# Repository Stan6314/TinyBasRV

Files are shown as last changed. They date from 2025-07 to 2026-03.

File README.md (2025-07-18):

Microcomputer TinyBasRV
======================

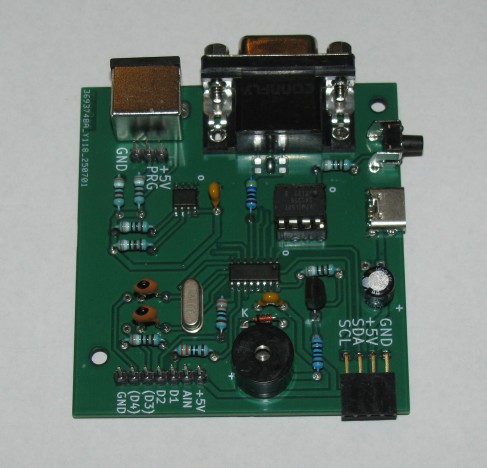
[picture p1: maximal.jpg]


The TinyBasRV microcomputer is a very simple device that even an electrical engineering beginner should be able to assemble and put into operation. It resembles simple 8-bit computers from the 1980s. After assembly, it can be programmed very easily using the Tiny BASIC language, which should be manageable even for those who have never programmed before. The basis is a small 32-bit RISC-V processor cooperating with serial I2C memory, where the user-created program is stored.

A microcomputer is suitable for the first introduction to computing technology when teaching hardware and software. It can be used not only for educational purposes, but can also be used as a control element for simple electronic devices.

Technical data for TinyBasRV
----------------------------

*   TinyBasHW_KiCad - HW documents (schematic and printed circuit board) in KiCad 9.0 format
*   src - Source files for TinyBasRV for CH32V003 created in MounRiver 2.10 environment
*   Bin - Compiled binary content in HEX format for direct loading into CH32V003 memory
*   Manuals - Manuals for HW, Tiny BASIC programming language and its examples and advice for beginners
*   EEPROM_examples - Contents of serial EEPROM memory in HEX format with examples of 8 ready-made Tiny BASIC sample programs for loading into microcomputer memory

Requirements for building and operating a TinyBasRV
---------------------------------------------------

*   Printed circuit board
*   Electrical components according to the list in the TinyBasHW manual
*   WCHLinkE programmer for programming CH32V003
*   Monitor with VGA input
*   Keyboard with PS2 connector
*   5V power supply

Using a microcomputer
---------------------

The assembled microcomputer only requires a 5 V power supply and a VGA monitor and PS2 keyboard connection. It is possible to use both a modern monitor and keyboard...

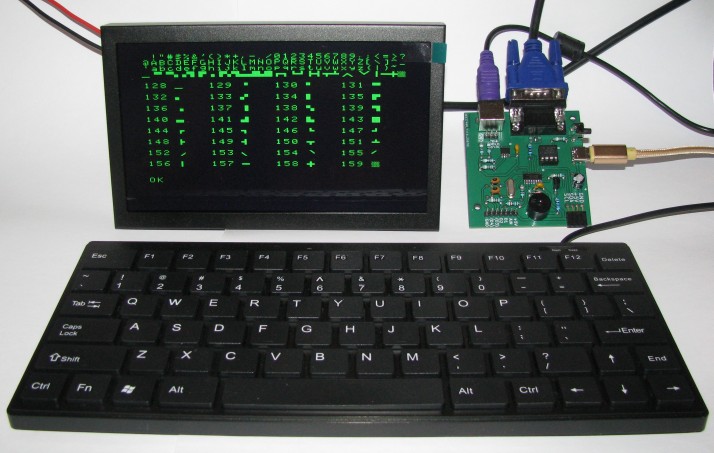
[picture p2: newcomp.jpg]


... so you can also create an old "retro" computer (if you can still find historical computer parts).

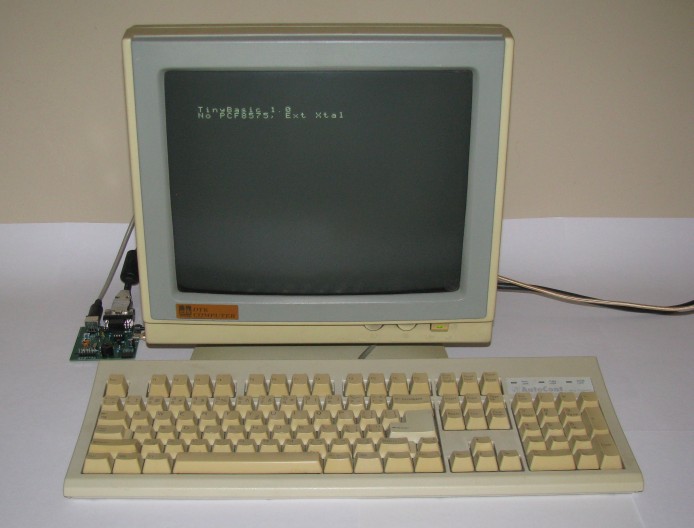
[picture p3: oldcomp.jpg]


After debugging the program, the TinyBasRV microcomputer can work independently without a monitor and keyboard and control, for example, some LED lighting effects.

* * *

Mikropočítač TinyBasRV
======================



Mikropočítač TinyBasRV je velmi jednoduché zařízení, které by měl dokázat sestavit a uvést do provozu i elektrotechnický začátečník. Podobá se jednoduchým 8bitovým počítačům z 80tých let. Po sestavení jej lze velmi jednoduše programovat pomocí jazyka Tiny BASIC, který by měl zvládnout i ten, kdo dříve neprogramoval. Základem je malý 32bitový RISC-V procesor spolupracující se sériovou I2C pamětí, kam se ukládá uživatelem tvořený program.

Mikropočítač je vhodný pro první seznámení s výpočetní technikou při výuce technického i programového vybavení. Může být použit nejen pro výukové účely, ale lze jej nasadit jako řídicí prvek pro jednoduché elektronické přístroje.

Technické podklady pro TinyBasRV
--------------------------------

*   TinyBasHW_KiCad - HW podklady (schéma a plošný spoj) ve formátu programu KiCad 9.0
*   src - Zdrojové soubory k TinyBasRV pro CH32V003 vytvořené v prostředí MounRiver 2.10
*   Bin - Přeložený binární obsah ve formátu HEX pro přímé nahrání do paměti CH32V003
*   Manuals - Manuály pro HW, programovací jazyk Tiny BASIC a jeho příklady a rady pro začátečníky
*   EEPROM_examples - Obsah sériové EEPROM paměti ve formátu HEX s příklady 8 hotových ukázkových programů Tiny BASIC pro nahrání do paměti mikropočítače

Požadavky pro stavbu a provoz TinyBasRV
---------------------------------------

*   Deska plošného spoje
*   Elektrotechnické součástky podle seznamu v manuálu TinyBasHW
*   Programátor WCHLinkE pro naprogramování CH32V003
*   Monitor s VGA vstupem
*   Klávesnice s konektorem PS2
*   Napájecí zdroj 5 V

Použití mikropočítače
---------------------

Sestavený mikropočítač vyžaduje pouze napájecí zdroj 5 V a připojení VGA monitoru a PS2 klávesnice. Je možné použít jak moderní monitor a klávesnici...



... tak si vytvořit i starý "retro" počítač (pokud ještě najdete dnes již historické počítačové díly).



Po odladění programu, může mikropočítač TinyBasRV pracovat samostatně bez monitoru a klávesnice a řídit např. nějaké světelné LED efekty.

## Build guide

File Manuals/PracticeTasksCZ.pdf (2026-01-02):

## Cvičné úlohy pro jazyk Tiny BASIC (ver 1)

Příklad 1:

Zadání:
Vytvořte program pro výpočet plochy obdélníka. Po spuštění programu bude uživatel vyzván, ať zadá délky stran. Pak se vypíše velikost plochy. Vše počítejte s celočíselnými hodnotami.

Rada:
Použijte příkazy PRINT a INPUT. Plocha obdélníka se vypočítá jako součin délek jeho stran.

Příklad řešení:
0 REM Vypocet plochy obdelnika 1 PRINT “Zadej delku stran:\n“ 2 INPUT A; INPUT B
3 PRINT “Plocha je: “ , A*B

Poznámky k řešení:
Příklad by se dal napsat i na jeden řádek:
1 INPUT A; INPUT B; PRINT “Plocha je: “ , A*B

Rev. C

Příklad 2:

Zadání:
Vytvořte program pro výpočet plochy kruhu s přesností na 2 desetinná místa. Po spuštění programu bude uživatel vyzván, ať zadá poloměr kruhu a pak se vypíše velikost plochy.

Rada:
Použijte příkazy PRINT, LET, IF-THEN a INPUT. Tiny BASIC počítá pouze s celými čísly. Použijte pro výpočet plochy hodnotu π jako 314 a pak zobrazte výsledek postupně. Nejprve vypište celou hodnotu získanou dělením 100, znak pro desetinnou čárku a pak zbytek po dělení 100. Nezapomeňte, že zbytek po dělení je nutné zobrazit i s první nulou – např. 08.
Vzorec pro výpočet plochy je známý:

Příklad řešení:
0 REM Vypocet plochy kruhu
1 PRINT “Zadej polomer:\n“
2 INPUT R
3 LET S=R*R*314; LET C=S/100 4 PRINT “Plocha je: “ , C, “.“
5 LET Z=S-C*100
6 IF Z<10 THEN PRINT “0“
7 PRINT Z

Poznámky k řešení:
Tiny BASIC nemá operaci pro mocniny čísel. Proto je druhá mocnina zapsána jako R*R (řádek 3). A také nepracuje s desetinnými čísly. Násobením 314 místo 3,14 získáme výsledek 100krát větší. Abychom dostali celou část výsledku musíme S dělit 100 (řádek 3). Zbytek, který vypočítáme po odečtení celočíselné části násobené 100, pak musíme zobrazit i s případnou první nulou (řádek 6).

Příklad 3:

Zadání:
Vytvořte program, který pod sebe vypíše všechna lichá čísla do 20.

Rada:
Použijte příkazy PRINT, LET, GOTO a IF-THEN

Příklad řešení:
0 REM Licha cisla do 20
1 LET A=1
2 PRINT A, “\n“
3 LET A=A+2
4 IF A<20 THEN GOTO 2

Poznámky k řešení:
Jde o velmi jednoduchý počítaný cyklus. Začínáme od 1 (řádek 1) a postupně čísla vypisujeme na samostatné řádky (řádek 2) se zvětšováním po 2 (řádek 3). Vyhodnocovací podmínka (řádek 4) vrací program na výpis čísla, dokud není dosažena 20.

Příklad 4:

Zadání:
Vytvořte program, který vykresli na obrazovce pravoúhlý trojúhelník ze znaků * vysoký 10 řádků.

Rada:
Použijte příkazy PUTCH, LET, GOTO a IF-THEN. Znak pro nový řádek má hodnotu 10 a znak * má hodnotu 42.

Příklad řešení:
0 REM Trojuhelnik z *
1 PUTCH 10
2 LET A=1; REM Pocita radky
3 LET B=1; REM Hvezdy na radku 4 PUTCH 42; LET B=B+1
5 IF B<=A THEN GOTO 4
6 PUTCH 10; LET A=A+1
7 IF A<11 THEN GOTO 3

Poznámky k řešení:
Jsou zde použity 2 počítané cykly vnořené do sebe. V proměnné A se počítají řádky (řádky 2,6,7) a v proměnné B se počítají znaky vypisované na řádku (řádky 3,4,5).

Příklad 5:

Zadání:
Vytvořte program, který vykresli na obrazovce čtverec o délce strany 10 znaků.

Rada:
Použijte příkazy PUTCH, PRINT, LET, GOTO a IF-THEN. Abyste si ušetřili práci, použijte pro vykreslení vodorovné čáry podprogram s příkazy GOSUB a RETURN. Nezapomeňte program ve správném bodě ukončit příkazem END.
Znak pro vymazání displeje má hodnotu 12, nový řádek 10, levý horní roh 144, pravý horní roh 145, levý dolní roh 146, pravý dolní roh 147, svislá čára 156 a vodorovná čára 157.

Příklad řešení:
0 REM Ctverec
1 PUTCH 12
2 LET A=1; REM Pocita radky 3 PUTCH 144; GOSUB 10
4 PUTCH 145; PUTCH 10
5 PUTCH 156; PRINT “ “
6 PUTCH 156; PUTCH 10; LET A=A+1 7 IF A<8 THEN GOTO 5
8 PUTCH 146; GOSUB 10
9 PUTCH 147; PUTCH 10; END
10 REM Vodorovna cara
11 LET I=1
12 PUTCH 157; LET I=I+1
13 IF I<9 THEN GOTO 12
14 RETURN

Poznámky k řešení:
Řádky 3 a 4 vykreslí horní stranu čtverce, řádky 8 a 9 spodek čtverce. Využívá se podprogram na řádcích 10 až 14, který dělá vodorovnou čáru. Řádky 5, 6 a 7 vykreslí svislé čáry. Počet mezer v příkazu PRINT na řádku 5 musí být 8, aby se vyprázdnilo tělo čtverce.

Příklad 6:

Zadání:
Vytvořte program, který umožní posunovat znak X po obrazovce. Začíná se uprostřed obrazovky a stisknutí klávesy 2 znak X posune dolů, 4 vlevo, 6 vpravo a 8 nahoru.

Rada:
Použijte příkaz PUTCH s využitím jeho parametrů, CURSOR, INKEY, GOTO a IF-THEN.
Znak pro vymazání displeje má hodnotu 12, znak X je 88, prázdný znak je 32, 2 je 50, 4 je 52, 6 je 54 a 8 je 56.

Příklad řešení:
0 REM Posun X
1 PUTCH 12
2 CURSOR 400; PUTCH .88
3 INKEY K
4 IF K=50 THEN PUTCH v32; PUTCH .88 5 IF K=52 THEN PUTCH <32; PUTCH .88 6 IF K=54 THEN PUTCH >32; PUTCH .88 7 IF K=56 THEN PUTCH ^32; PUTCH .88
8 GOTO 3

Poznámky k řešení:
Program nejprve vyčistí obrazovku a umístí doprostřed displeje (pozice 400) znak X pomocí příkazu PUTCH. Symbol tečky zajistí, že kurzor zůstane na dané pozici. Když uživatel stiskne správnou klávesu, nejprve se vymaže stará pozice prázdným znakem a posune se kurzor na novou pozici (směr určuje symbol před hodnotou 32). Na nové pozici se pak vypíše X a ponechá kurzor.

Příklad 7:

Zadání:
Vytvořte program, který bude automaticky „hrát ping-pong“. Míček v podobě písmene o bude poletovat na řádku z levé strany na pravou stranu a naopak. Na kraji displeje se vždy odrazí a vrátí zpět.

Rada:
Použijte příkaz PUTCH s využitím parametrů, CURSOR, DELAY, GOTO a IF-THEN.
Znak pro vymazání displeje má hodnotu 12, znak o je 111, prázdný znak je 32.
Pozice uprostřed prostředního řádku má hodnotu 400, znak na levém okraji 384, vpravo 415.

Příklad řešení:
0 REM Ping-pong
1 PUTCH 12; LET C=400
2 CURSOR C; PUTCH .111
3 LET D=1
4 DELAY 100; PUTCH .32
5 LET C=C+D; CURSOR C; PUTCH .111 6 IF C=415 THEN LET D=-1
7 IF C=384 THEN LET D=1
8 GOTO 4

Poznámky k řešení:
Nejprve se program nastaví do výchozí pozice a směr pohybu míčku v proměnné D se určí na hodnotu 1 – tj. míček poletí vpravo(řádky 1 až 3). Ve smyčce, která začíná na řádku 4, se chvíli počká, smaže starý obraz míčku a pak se posune míček podle hodnoty v D na novou pozici. Řádky 6 a 7 hlídají dosažení kraje obrazovky a mění směr letu tam (D=1), nebo zpět (D=-1).

Příklad 8:

Zadání:
Napište program, který zahraje melodii podle not na obrázku. Na začátku uživatel zadá dobu trvání 1/8 noty v rozmezí 200 až 400 milisekund.

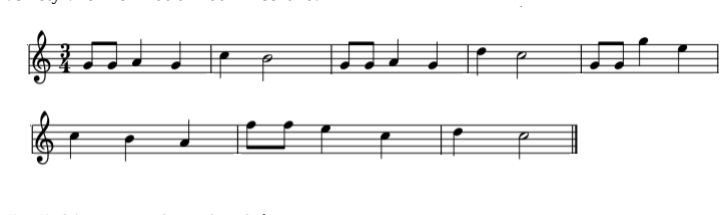
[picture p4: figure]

Přibližné frekvence základních tónů:
c‘: 262 | d‘: 294 | e‘: 330 | f‘: 349 | g‘: 392 | a‘: 440 | h‘: 494
c“: 523 | d“: 587 | e“: 659 | f“: 698 | g“: 784 | a“: 880 | h“: 989

Rada:
Použijte příkaz BEEP s využitím parametrů, INPUT, GOTO a IF-THEN. Pokud se v melodii objevují stejné pasáže, můžete použít podprogram GOSUB a RETURN, abyste nemuseli opisovat stejné části. Nezapomeňte program ukončit příkazem END.

Příklad řešení:
0 REM Melodie
1 PRINT “Zadej tempo:\n“
2 INPUT T
3 IF T<200 THEN GOTO 1
4 IF T>400 THEN GOTO 1
5 GOSUB 15
6 BEEP 523,2*T; BEEP 494,4*T; GOSUB 15 7 BEEP 587,2*T; BEEP 523,4*T; BEEP 392,T 8 BEEP 392,T; BEEP 784,2*T; BEEP 659,2*T
9 BEEP 523,2*T; BEEP 494,2*T; BEEP 440,2*T 10 BEEP 698,T; BEEP 698,T; BEEP 659,2*T
11 BEEP 523,2*T; BEEP 587,2*T; BEEP 523,4*T 12 END
15 BEEP 392,T; BEEP 392,T; BEEP 440,2*T
16 BEEP 392,2*T; RETURN

Poznámky k řešení:
Uživatel je nejprve vyzván k zadání tempa a je zkontrolováno povolené rozmezí hodnot (řádky 1 až 4). Protože se první čtyři tóny opakují ve třetím taktu, je použit podprogram na řádcích 15 a 16. Jednotlivé tóny jsou zadány frekvencí a dobou trvání. Čtvrťová nota je dvojnásobná a půlová čtyřnásobná proti zadané době osminové noty.

Příklad 9:

Zadání:
Napište program pro vytvoření velmi jednoduchého klavíru. Po stisknutí klávesy 1 až 9 zahraje po dobu 200 až 600 milisekund (čas se zadá po startu) tón c‘ až d“.
Přibližné frekvence základních tónů:
c‘: 262 | d‘: 294 | e‘: 330 | f‘: 349 | g‘: 392 | a‘: 440 | h‘: 494
c“: 523 | d“: 587

Rada:
Použijte příkaz BEEP s využitím parametrů, INPUT, INKEY, GOTO a IF-THEN. Zkuste využít toho, že klávesy 1 až 9 vrací v příkazu INKEY hodnoty 49 až 57. Pak můžete vypočítat potřebný skok v příkazu GOTO.

Příklad řešení:
0 REM Piano
1 PRINT “Zadej dobu tonu:\n“ 2 INPUT T
3 IF T<200 THEN GOTO 1
4 IF T>600 THEN GOTO 1
5 INKEY K
6 IF K<49 THEN GOTO 5
7 IF K>57 THEN GOTO 5
8 GOTO K-40
9 BEEP 262,T; GOTO 5
10 BEEP 294,T; GOTO 5
11 BEEP 330,T; GOTO 5
12 BEEP 349,T; GOTO 5
13 BEEP 392,T; GOTO 5
14 BEEP 440,T; GOTO 5
15 BEEP 494,T; GOTO 5
16 BEEP 523,T; GOTO 5
17 BEEP 587,T; GOTO 5

Poznámky k řešení:
Uživatel je nejprve vyzván k zadání doby tónu a je zkontrolováno povolené rozmezí hodnot (řádky 1 až 4). Ve smyčce, která začíná na řádku 5 se nejprve zkontroluje, zda klávesa patří mezi povolené a pak se vypočítá na řádku 8 skok na řádek s odpovídajícím tónem. Hodnota první povolené číslice 49 musí zamířit na řádek 9, proto se odečítá hodnota 40.

Příklad 10:

Zadání:
Vytvořte program, který bude představovat losovací zařízení pro čísla 1 až 49. Vždy po stisknutí libovolné klávesy zobrazí náhodné číslo z uvedeného rozsahu.

Rada:
Použijte příkazy TIME, INKEY, PRINT, GOTO a IF-THEN.
Po stisknutí klávesy vezměte aktuální čas. Jeho zbytek po dělení 49 bude dostatečně náhodné číslo. Nezapomeňte, že zbytek po dělení 49 je v rozsahu 0 až 48. Získanou hodnotu je potřeba zvýšit o 1.

Příklad řešení:
0 REM Nahodne cislo
1 INKEY K
2 IF K=0 THEN GOTO 1
3 TIME T; LET A=T/49
4 PRINT T-A*49+1, “\n“
5 GOTO 1

Poznámky k řešení:
Na řádcích 1 a 2 se čeká na stisknutí libovolné klávesy. V okamžiku, kdy uživatel stiskne klávesu se naplní proměnná T příkazem TIME. Hodnota získaná příkazem TIME se mění přibližně 32000krát za sekundu. Protože potřebujeme náhodná čísla do 49, vypočítáme zbytek po dělení 49. Výsledek zvětšený o 1 zobrazíme.

Příklad 11:

Zadání:
Vytvořte program ukazující čas uplynulý od spuštění počítače ve formě HH:MM:SS.

Rada:
Použijte příkazy TIME, PRINT, PUTCH, CURSOR, GOTO a IF-THEN.
Pokud hodnotu získanou příkazem TIME podělíte 31914, získáte čas od spuštění počítače v sekundách. Získaný čas pak stačí dělit 3600, abyste dostali počet uplynulých hodin. Ze zbytku pak dělením 60 získáte minuty. Nezapomeňte, že v zadání je zobrazení čísla na 2 místa. Nestačí vypsat jenom např. 5, je třeba zobrazit jako 05. Na to se může hodit podprogram s GOSUB a RETURN. Znak : má hodnotu 58, znak 0 má hodnotu 48.

Příklad řešení:
0 REM Hodiny
1 PUTCH 12
2 DELAY 300
3 TIME T; LET S=T/31914
4 LET A=S/3600; LET S=S-A*3600 5 CURSOR 0; GOSUB 10
6 LET A=S/60; LET S=S-A*60
7 PUTCH 58; GOSUB 10
8 LET A=S; PUTCH 58; GOSUB 10 9 GOTO 2
10 REM Vypis z A na 2 mista
11 IF A<10 THEN PUTCH 48
12 PRINT A; RETURN

Poznámky k řešení:
Čas získaný příkazem TIME podělíme hodnotou 31914, abychom získali celkový čas v sekundách. Hodiny do proměnné A získáme dělením 3600. Ve zbytku po celočíselném dělení zůstanou minuty a sekundy. Celočíselným dělením 60 dostaneme minuty a zbytek z výpočtu minut jsou sekundy. Vše musíme zobrazovat na 2 místa, takže doplňujeme případnou první nulu u jednociferných čísel při zobrazování hodnoty z A v podprogramu (řádek 11).

Příklad 12:

Zadání:
Vytvořte pomocí počítače „kuchyňskou minutku“. Po startu programu uživatel zadá čas od 1 do 99 minut. Po zadání začne na displeji odpočítávání po minutách a po dosažení 0 se ozve 10 sekund signál.

Rada:
Použijte příkaz TIME, BEEP, INPUT, PRINT, GOTO a IF-THEN. Po zadání požadovaného času si můžete vypočítat čas, při kterém časování skončí. Cílový čas získáte přičtením počtu minut násobených 60*31914 (sekundy v minutě krát počet tiků za sekundu = 1914840) k aktuálnímu času.

Příklad řešení:
0 REM Minutka
1 PRINT “Zadej cas [min]:\n“ 2 INPUT T
3 IF T<1 THEN GOTO 1
4 IF T>99 THEN GOTO 1
5 TIME C; LET C=C+T*60*31914 6 PUTCH 12
7 DELAY 300
8 TIME T; LET D=C-T
9 IF D<0 THEN BEEP 800,10000; END 10 CURSOR 0; PRINT D/1914840, “ “
11 GOTO 7

Poznámky k řešení:
Uživatel je nejprve vyzván k zadání doby a je zkontrolováno povolené rozmezí hodnot (řádky 1 až 4). Po správném zadání je do proměnné C uložen cílový čas, který vypočítáme jako aktuální čas s dobou zadanou uživatelem vynásobenou 31914 (počet tiků za sekundu) a 60 (počet sekund v minutě). Ve smyčce, která začíná na řádku 7, chvíli čekáme, protože není nutno zobrazovat hodnoty tak rychle, že by to uživatel stejně nepostřehl. Na řádku 8 zjistíme rozdíl mezi cílovým a aktuálním časem. Při záporném výsledku časování ukončíme. Jinak rozdíl zobrazíme. Konstanta 1914840 vznikne vynásobením 60*31914.

Příklad 13:

Zadání:
Naprogramujte hru „Lepší postřeh“ pro dva a více hráčů. Po stisknutí klávesy čeká 5 sekund, přičemž start časování je zahájen *. Pak zobrazí na displeji cílový znak. Klávesa, která byla zmáčknutá jako první po zobrazení cílového znaku, bude označena jako vítěz.

Rada:
Použijte příkazy INKEY, DELAY, PUTCH, PRINT, GOTO a IF-THEN. Při tvorbě programu nezapomeňte na to, že musíte zkontrolovat, zda hráč nezmáčknul klávesu před zobrazením cílového znaku.
Znak * má hodnotu 42, cílový znak má hodnotu 143.

Příklad řešení:
0 REM Lepsi postreh
1 PRINT “\nStart hry\n“
2 INKEY K
3 IF K=0 THEN GOTO 2
4 PUTCH 42; DELAY 5000; INKEY K 5 PUTCH 143; IF K>0 THEN GOTO 10
6 INKEY K
7 IF K=0 THEN GOTO 6
8 PRINT “\nVitez: “; PUTCH K; DELAY 2000 9 GOTO 1
10 PRINT “\nProhral: “; PUTCH K; DELAY 2000
11 GOTO 1

Poznámky k řešení:
Na řádcích 1 až 3 počkáme na start hry. Pak zobrazíme *, čekáme 5 sekund a sejmeme, zda někdo nestiskl klávesu předčasně (řádek 4). Na řádku 5 zobrazíme cílový znak a zkontrolujeme předčasné stisknutí klávesy. Je-li vše v pořádku, na řádcích 6 a 7 čekáme na stisknutí klávesy a na řádku 8 vyhlásíme vítěze.

Příklad 14:

Zadání:
Vytvořte program pro akustický generátor. Uživatel zadá frekvenci požadovaného tónu v rozsahu 100 až 4000 Hz a dokud nebude program ukončen, počítač píská zadaným tónem.

Rada:
Použijte příkazy BEEP, INPUT, PRINT, GOTO a IF-THEN.
Aby bylo možné program zastavit zadáním příkazu END, použijte v časovém parametru u příkazu BEEP nějakou přijatelnou hodnotu v rozsahu jednotek sekund.

Příklad řešení:
0 REM Zvukovy generator
1 PRINT “Zadej frekv. 100-4000\n“ 2 INPUT F
3 IF F<100 THEN GOTO 1
4 IF F>4000 THEN GOTO 1
5 BEEP F,5000
6 GOTO 5

Poznámky k řešení:
Uživatele nejprve vyzveme k zadání frekvence a je zkontrolováno povolené rozmezí hodnot (řádky 1 až 4). Pak je ve smyčce na řádcích 5 a 6 trvale pouštěn tón o zadané frekvenci.

Příklad 15:

Zadání:
Napište program, ve kterém uživatel zadá nějaké jméno ukončené klávesou Enter. Počítač pak vypíše, že jméno je jeho přítel. Maximální délka jména může být 30 znaků.

Rada:
Použijte příkazy INKEY, PRINT, PUTCH, GOTO a IF-THEN. Zadávané jméno je výhodné ukládat do proměnných v poli @. Počítejte si přitom počet uložených písmen.

Příklad řešení:
0 REM Pritel pocitace
1 LET I=0; PRINT “\nZadej jmeno:\n“ 2 INKEY K
3 IF K=0 THEN GOTO 2
4 IF K=10 THEN GOTO 10
5 PUTCH K; LET @I=K; LET I=I+1 6 IF I=30 THEN GOTO 10
7 GOTO 2
10 LET J=0; PUTCH 10
11 PUTCH @J; LET J=J+1
12 IF J<I THEN GOTO 11
13 PRINT “ je muj pritel\n“

Poznámky k řešení:
Řádky 2 a 3 čekají na zadání znaku. Řádek 4 kontroluje, zda nebylo zadávání ukončeno klávesou Enter. Na řádku 5 je znak uložen do pole. Řádek 6 kontroluje maximální povolenou délku jména. Na řádcích 10 až 12 je jméno opět vypsáno.

Příklad 16:

Zadání:
Vytvořte program pro ovládání LED připojené k výstupu D1 pomocí klávesnice. První zmáčknutí libovolné klávesy LED rozsvítí, druhé zhasne, další opět rozsvítí atd.

Doplňkový HW:
Na výstup D1 připojte LED s rezistorem podle následujícího obrázku. Červená barva LED bude vhodná pro následující úlohu.

Rada:

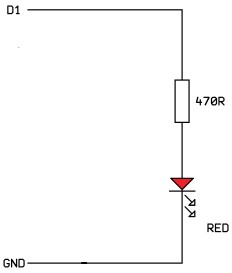
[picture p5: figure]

Použijte příkazy INKEY, DOUT, GOTO a IF-THEN. Příkaz DOUT 1,1 pak LED rozsvítí a DOUT 0,1 ji zhasne.
Protože program nemusí být rychlý, můžete do cyklu čekání na stisk klávesy vložit drobné zpoždění příkazem DELAY.

Příklad řešení:
0 REM Ovladani LED
1 LET L=0
2 DELAY 100; INKEY K
3 IF K=0 THEN GOTO 2
4 IF L=0 THEN GOTO 6
5 LET L=0; DOUT 0,1; GOTO 2
6 LET L=1; DOUT 1,1; GOTO 2

Poznámky k řešení:
Proměnná L ukládá aktuální hodnotu výstupu, abychom věděli, jak příště výstup změnit. Na řádcích 2 a 3 se čeká na stisk klávesy. Řádek 4 rozhodne podle stavu L, zda se LED rozsvítí nebo zhasne.

Příklad 17:

Zadání:
Vytvořte program, který z TinyBasRV udělá ovládání výstražných světel na železničním přejezdu i se zvukovou signalizací.

Doplňkový HW:
Na výstupy D1 a D2 připojte dvě LED (nejlépe červené) s rezistory podle následujícího obrázku.

Rada:

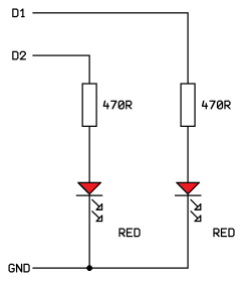
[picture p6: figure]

Použijte příkazy BEEP, DELAY, DOUT a GOTO. Zvukovou signalizaci si vyzkoušejte a upravte podle vlastních představ.

Příklad řešení:
0 REM Zeleznice - vystraha
1 DOUT 1,1; DOUT 0,2
2 BEEP 2000,100; BEEP 800,200; DELAY 200 3 DOUT 0,1; DOUT 1,2
4 BEEP 2000,100; BEEP 800,200; DELAY 200
5 GOTO 1

Poznámky k řešení:
Řádky 1 a 3 rozsvítí vždy pouze jednu z obou LED. Na řádcích 2 a 4 je generováno stejné zvukové znamení. Uvedený příklad jen velmi vzdáleně připomíná cinkání zvonce. Můžete je ladit a upravovat podle svého ucha...

Příklad 18:

Zadání:
Vytvořte program pro měření vstupního napětí na vstupu AIN v mV. Na vstup přiveďte napětí z běžce potenciometru, které bude zobrazováno s periodou ½ sekundy.

Doplňkový HW:
Na výstup AIN připojte lineární potenciometr s hodnotou odporu v rozmezí 1 až 100 kΩ podle následujícího obrázku.

Rada:

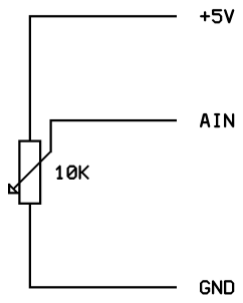
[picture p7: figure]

Použijte příkazy AINP, DELAY, CURSOR, PRINT a GOTO. Hodnota získaná z A/D převodníku je v rozsahu 0 až 1023. To představuje napětí 0 až 5V – tedy 0 až 5000 mV. Abychom přepočítali rozsah A/D převodníku na mV, musíme hodnotu nejprve vynásobit 5000 a pak dělit 1023.

Příklad řešení:
0 REM Analog vstup mV
1 PUTCH 12
2 CURSOR 397; AINP A
3 PRINT A*5000/1023, “ mV “ 4 DELAY 500
5 GOTO 2

Poznámky k řešení:
Na řádku 2 se nejprve nastaví kurzor přibližně do středu obrazovky a pak se změří napětí na vstupu AIN. Přepočet se provede při výpisu hodnoty v příkaze PRINT podle návodu v odstavci Rada. Po výpisu jednotek jsou ještě doplněny 3 mezery, aby se vymazal případný delší zápis z minulého měření.

Příklad 19:

Zadání:
Upravte počítač TinyBasRV tak, aby pracoval jako jednoduchý voltmetr s rozsahem do 50 V. Napětí bude zobrazováno s periodou ½ sekundy a s rozlišením na 2 desetinná místa.

Doplňkový HW:
Na výstup AIN připojte vstupní odporový dělič s rezistory s poměrem odporů 9:1. Ideální by bylo např. 900 kΩ a 100 kΩ. Hodnota 900 kΩ je ale mimo běžnou řadu dostupných rezistorů. Můžete použít nejbližší hodnotu 910 kΩ z řady E24. V nouzi lze použít i 1 MΩ a upravit konstantu v programu.

Rada:

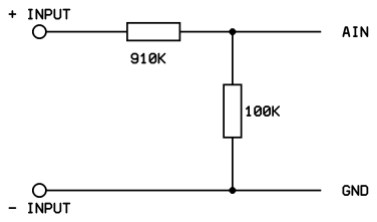
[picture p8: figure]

Použijte příkazy AINP, DELAY, CURSOR, PUTCH, PRINT, GOTO a IF-THEN. Hodnota získaná AINP z A/D převodníku je v rozsahu 0 až 1023. To představuje napětí 0 až 50V (musíme zobrazit 0.00 až 50.00 V). Abychom přepočítali rozsah A/D převodníku na V, je třeba hodnotu nejprve vynásobit 5000 a pak dělit 1023. Výsledné číslo zobrazíme s desetinou tečkou mezi číslicemi. Násobící konstanta 5000 je ideální případ, kdy se předpokládá přesné referenční napětí v mikropočítači a přesné hodnoty odporu obou rezistorů v děliči. V praxi se to bude lišit. Proto je potřeba u konkrétního kusu počítače tuto hodnotu upravit tak, aby zobrazené napětí se co nejvíce blížilo napětí změřenému referenčním voltmetrem.

Příklad řešení:
0 REM Voltmetr 50V
1 PUTCH 12; LET K=5320
2 CURSOR 397; AINP A
3 LET V=A*K/1023; LET C=V/100 4 LET Z=V-C*100
5 PRINT C, “.“
6 IF Z<10 THEN PRINT “0“
7 PRINT Z
8 DELAY 500
9 GOTO 2

Poznámky k řešení:
Na řádku 1 je nastavena přepočtová konstanta, kterou si musíte upravit podle konkrétního kusu počítače a vstupního odporového děliče. Další postup již kopíruje instrukce uvedené v odstavci Rada. Nejprve je vypsána celá část z proměnné C a pak zbytek po dělení 100 ze Z. Pokud je zbytek menší než 10, je nutné doplnit úvodní nulu (řádek 6).

Příklad 20:

Zadání:
Pomocí expanderu PCF8575 připojeného k TinyBasRV vyrobte běžící světlo na řadě LED připojených k výstupům expanderu.

Doplňkový HW:
Na výstupy modulu s expanderem PSC8575 připojte více LED podle obrázku. Záleží na množství LED, které máte k dispozici, maximálně je možné připojit 16 LED.

Rada:

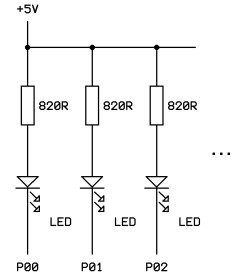
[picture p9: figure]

Použijte příkazy I2CW, DELAY, LET, GOTO a IF-THEN. Pokud chcete rozsvítit první LED, musíte do expanderu poslat binární číslo b1111111111111110 nebo dekadicky -2. Druhá LED vyžaduje poslat binární číslo b1111111111111101 nebo dekadicky -3. Další by bylo binární číslo b1111111111111011 nebo dekadicky -5. Rozsvícení LED se posune na další pozici vždy vynásobením 2 a přičtením 1.
Po rozsvícení poslední LED se musí světlo vrátit na začátek.

Příklad řešení (pro 8 LED): 0 REM Bezicich 8 LED
1 LET A=-2
2 I2CW A; DELAY 200
3 LET A=A*2+1
4 IF A < -300 THEN LET A=-2
5 GOTO 2

Poznámky k řešení:
Program postupuje podle instrukcí uvedených v odstavci Rada. Po daný příklad bylo použito pouze 8 LED, při dosažení hodnoty menší než -300 se hodnota v A vrátí na začátek. Poslání čísla -257 do expanderu (poslední odeslané v cyklu) na chvíli vypne všech 8 LED. Pokud byste to nechtěli, zmenšete podmínku např. na A<-150.

Příklad 21:

Zadání:
Napište program, který pomocí expanderu PCF8575 připojeného k TinyBasRV rozsvítí po stisknutí klávesy 0 až 9 určený počet LED (vámi zvolený obraz).

Doplňkový HW:
Na výstupy modulu s expanderem PSC8575 připojte více LED podle obrázku. Záleží na množství LED, které máte k dispozici, maximálně je možné připojit 16 LED.

Rada:

Použijte příkazy I2CW, DELAY, INKEY, GOTO a IF-THEN. Pro jednotlivé číslice si můžete určit libovolný vzorek rozsvícených LED. Např. po stisknutí klávesy 1 se rozsvítí každá lichá LED příkazem I2CW b1010101010101010, klávesa 2 rozsvítí dolní polovinu LED příkazem I2CW b1111111100000000 atd.
Klávesy 0 až 9 vrací v příkazu INKEY hodnoty 48 až 57.

Příklad řešení:
0 REM Vzory z LED
1 DELAY 100; INKEY K
2 IF K<48 THEN GOTO 1
3 IF K>57 THEN GOTO 1
4 GOTO K-43
5 I2CW b1100110011001100; GOTO 1 6 I2CW b1010101010101010; GOTO 1 7 I2CW b1111111100000000; GOTO 1 8 I2CW b1111100001100101; GOTO 1 9 I2CW b0000000011001100; GOTO 1 10 I2CW b1100110000000000; GOTO 1 11 I2CW b1110111011101110; GOTO 1 12 I2CW b1101110111011101; GOTO 1 13 I2CW b1011101110111011; GOTO 1
14 I2CW b0111011101110111; GOTO 1

Poznámky k řešení:
Nejprve se na řádcích 1, 2 a 3 zajistí přijetí pouze povolené číselné klávesy. Řádek 4 pak zajistí odskok na patřičný vzorek rozsvícených LED s návratem na začátek.

Příklad 22:

Zadání:
Naprogramujte měřič postřehu uživatele. Po stisknutí klávesy čeká program náhodný počet sekund (1 až 10), přičemž start časování je zahájen *. Pak zobrazí na displeji cílový znak. Uživatel musí co nejrychleji zmáčknout libovolnou klávesu. Na displeji se zobrazí reakční čas v milisekundách.

Rada:
Použijte příkazy INKEY, TIME, DELAY, PUTCH, PRINT, GOTO a IF-THEN. Při tvorbě programu nezapomeňte na to, že musíte zkontrolovat, zda hráč nezmáčknul klávesu před zobrazením cílového znaku. Pro měření času v milisekundách budeme počítat, že TIME vrací každou milisekundu hodnotu o 32 větší.
Znak * má hodnotu 42, cílový znak má hodnotu 143.

Příklad řešení:
0 REM Meric postrehu
1 PRINT “\nStart\n“
2 INKEY K
3 IF K=0 THEN GOTO 2
4 TIME T; LET C=T/10
5 LET D=T-C*10+1; LET D=D*1000 6 PUTCH 42; DELAY D
7 INKEY K; PUTCH 143; TIME S 8 IF K>0 THEN GOTO 14
9 INKEY K
10 IF K=0 THEN GOTO 9
11 TIME E; LET R=E-S
12 PRINT “\nReakce: “, R/32 13 PRINT “ milisec“; GOTO 1 14 PRINT “\nPredcasne!“
15 GOTO 1

Poznámky k řešení:
Řádky 2 a 3 čekají na start měření. Pak se získá pomocí příkazu TIME a zbytku po dělení 10 náhodný čas, který se uloží do proměnné D v milisekundách (řádky 4 a 5). Na řádku 6 se zobrazí * a provede čekání. Řádek 7 sejme stav kláves, zobrazí cílový znak a uloží začáteční čas pro měření postřehu. Na řádku 8 se zkontroluje případné předčasné stisknutí klávesy. Řádky 9 a 10 čekají na reakci uživatele. Čas, kdy zareagoval se uloží do E a pak na řádcích 11, 12 a 13 se výsledek vypíše.

Příklad 23:

Zadání:
Máte-li možnost připojit k TinyBasRV jehličkovou tiskárnu s paralelním portem přes expander PCF8575, vytvořte z ní jednoduchý psací stroj.

Doplňkový HW:
Na výstupy modulu s expanderem PCF8575 připojte konektor Cannon 25 samici podle obrázku.

Rada:

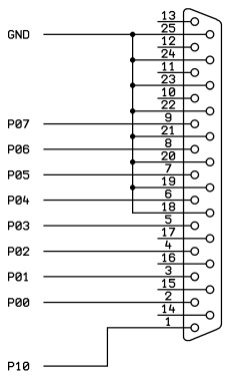
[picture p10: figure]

Použijte příkazy I2CW, DELAY, INKEY, GOTO a BEEP. Příkaz BEEP se použije pro zvukovou signalizaci stisknutí klávesy krátkým pípnutím. Není nutné jej použít.
Na vývodu 1 paralelního portu je signál STROBE ovládaný výstupem P10, který potvrdí a zapíše data do tiskárny. Aktivní hodnota je logická 0. Po zapsání dat, je nutné tento signál vrátit do klidové hodnoty 1. To lze nejsnáze udělat zapsáním hodnoty o 256 větší než zapisovaná data.

Příklad řešení:
0 REM Psaci stroj
1 INKEY K
2 IF K=0 THEN GOTO 1
3 I2CW K; PUTCH K
4 DELAY 10
5 I2CW K+256; BEEP 1000,50
6 GOTO 1

Poznámky k řešení:
Řádky 1 a 2 čekají na stisk klávesy. Řádek 3 pošle znak do tiskárny a okopíruje ho na displej. Na řádku 4 se chvíli počká (pro případ pomalé reakce tiskárny). Na řádku 5 se musí nastavit signál STROBE pro tiskárnu zpět na logickou 1 (hodnota znaku se zvýší o 9tý bit nastavený na 1) a krátce se pípne.

Příklad 24:

Zadání:
Vytvořte z TinyBasRV jednoduchou celočíselnou kalkulačku. Uživatel zadá první číslo, pak operand (+ - * /) a na závěr druhé číslo. Na displeji se objeví vypočítaný výsledek ve tvaru např. 256*2=512.

Rada:
Použijte příkazy INPUT, INKEY, PRINT, PUTCH, GOTO a IF-THEN. Znaky operandů mají následující hodnoty:
+ | 43 | - | 45 | * | 42 | / | 47
Nezapomeňte, že nulou nedělíme!

Příklad řešení:
0 REM Kalkulacka
1 PUTCH 10; INPUT A
2 INKEY K
3 IF K=42 THEN GOTO 8
4 IF K=43 THEN GOTO 8
5 IF K=45 THEN GOTO 8
6 IF K=47 THEN GOTO 8
7 GOTO 2
8 PUTCH K; PUTCH 10; INPUT B;
9 PRINT A; PUTCH K; PRINT B
10 IF K=43 THEN PRINT “=“,A+B; GOTO 1
11 IF K=45 THEN PRINT “=“,A-B; GOTO 1
12 IF K=42 THEN PRINT “=“,A*B; GOTO 1
13 IF B=0 THEN PRINT “ Nulou nelze!“; GOTO 1
14 PRINT “=“,A/B; GOTO 1

Poznámky k řešení:
První hodnota se uloží do proměnné A na řádku 1. Pak se na řádcích 3 až 7 čeká na typ operace. Na řádku 8 vytiskneme znak operace a počkáme na druhou hodnotu. Řádky 10 až 14 provedou výpočet podle stavu K, přičemž se na řádku 13 zkontroluje, zda se nebude dělit 0.

Příklad 25:

Zadání:
Napište program pro hádání tajného čísla 0 až 99. Po startu si počítač vybere náhodné číslo a hráč má toto číslo uhodnout na co nejmenší počet pokusů. Po každém pokusu počítač uvede, zda je tajné číslo větší nebo menší než to, které zadal hráč.

Rada:
Použijte příkazy INPUT, PRINT, TIME, LET, GOTO a IF-THEN. Nejprve si vygenerujte pomocí příkazu TIME a zbytku po dělení 100 náhodné číslo.

Příklad řešení:
0 REM Hadani cisla
1 TIME T; LET C=T/100; LET X=T-C*100 2 LET P=0; PRINT “\nHadej cislo\n“
3 INPUT A; LET P=P+1
4 IF A=X THEN GOTO 8
5 IF A>X THEN GOTO 7
6 PRINT P,“. Hadej vic\n“; GOTO 3
7 PRINT P,“. Hadej mene\n“; GOTO 3
8 PRINT “Uhodl jsi na “, P, “ pokusu\n“

Poznámky k řešení:
Na řádku 1 se pomocí příkazu TIME a zbytku po celočíselném dělení 100 uloží do proměnné X náhodně generované hádané číslo. Na řádcích 2 a 3 je uživatel vyzván k pokusu uhodnout číslo a v proměnné P se počítají provedené pokusy. Řádky 4 a 5 kontrolují úspěšnost pokusu a na zbývajících řádcích se vypisuje pokyn, kam směřovat další odhad nebo ukončení programu s výsledkem.

Příklad 26:

Zadání:
Vytvořte z TinyBasRV jednoduchý kódový zámek. Zadá-li uživatel na klávesnici správnou posloupnost 4 nebo 5 číslic, na výstupu D1 se na 3 sekundy objeví logická 1 a zazní zvukový signál.

Rada:
Použijte příkazy INKEY, LET, DOUT, BEEP, GOTO a IF-THEN. Počet kódových číslic si můžete zvolit sami. Tajnou číselnou kombinaci si uložte do pole @ a každá správně uhodnutá číslice posune ukazatel v poli na vyšší hodnotu. Při chybě se ukazatel vrátí na počátek pole.
Klávesy 0 až 9 vrací v příkazu INKEY hodnoty 48 až 57.

Příklad řešení:
0 REM Kodovy zamek
1 LET @0=49,57,50,48,51
2 LET P=0
3 INKEY K
4 IF K=0 THEN GOTO 3
5 IF K<>@P THEN GOTO 2
6 LET P=P+1;
7 IF P<5 THEN GOTO 3
8 DOUT 1,1; BEEP 800,3000; DOUT 0,1
9 GOTO 2

Poznámky k řešení:
Na řádku 1 je do pole @ uložen kód zámku. Proměnná P ukazuje, kam se uživatel při zadávání kódu dostal. Řádek 5 rozhoduje, zda se postoupí na další pozici, nebo se vrátí opět na první číslici kódu. Na řádku 7 se při správném postupu a dosažení ukazatele P na hodnotu 5 umožní přejít na řádek 8, kde se kódový zámek na 3 sekundy otevře.

Příklad 27:

Zadání:
Napište program, který bude nahrazovat hrací kostku. Program bude na displeji zobrazovat body tak, jak se nacházejí na kostce.

Rada:
Pokud se podíváte na vzory nacházející se na stěnách kostky, zjistíte, že kromě střední tečky se tečky vždy vyskytují po dvojicích. Např. 3 je kombinace A+B, 5 je A+B+C.

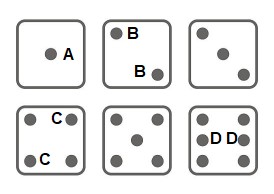
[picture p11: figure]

Vzory si můžete zakódovat do pole např. pomocí binárních čísel a pak je podle náhodně taženého čísla zobrazit. Doporučené pozice kurzoru jsou pro A: 400, pro B: 235 a 565, pro C: 245 a 555 a pro D: 395 a 405. Použijte příkazy LET, TIME, INKEY, GOTO, CURSOR, PUTCH a IF-THEN.

Příklad řešení:
0 REM Hraci kostka
1 PUTCH 12; LET @0=1,2,3,6,7,14
2 INKEY K
3 IF K=0 THEN GOTO 2
4 TIME D; LET C=D/6; LET D=D-C*6
5 CURSOR 400; PUTCH .32; IF @D&1 THEN PUTCH 143 6 CURSOR 235; PUTCH 32; CURSOR 565
7 PUTCH .32; IF@D&2 THEN PUTCH 143
8 CURSOR 235; IF@D&2 THEN PUTCH 143
9 CURSOR 245; PUTCH 32; CURSOR 555 10 PUTCH .32; IF@D&4 THEN PUTCH 143 11 CURSOR 245; IF@D&4 THEN PUTCH 143 12 CURSOR 395; PUTCH 32; CURSOR 405 13 PUTCH .32; IF@D&8 THEN PUTCH 143 14 CURSOR 395; IF@D&8 THEN PUTCH 143
15 GOTO 2

Poznámky k řešení:
V poli @ je zakódováno zobrazení čísel 0 až 5 pomocí binárního kódu. Pokud se podíváte, jak se uvedená čísla zapisují ve dvojkové soustavě, zjistíte, že nejnižší bit představuje tečku A, vyšší bit obě tečky B, další C a čtvrtý bit jsou tečky D. Řádky 2 a 3 čekají na stisknutí klávesy. Na řádku 4 je vygenerováno do proměnné D náhodné číslo 0 až 5. Pak jsou procházeny všechny pozice jednotlivých teček. Např. u řádku 5 je kurzor nastaven na tečku A a ta je nejprve smazána. Pokud prvek pole s indexem D má nastavený nejnižší bit, je tečka na pozici vykreslena.

Příklad 28:

Zadání:
Doplňte TinyBasRV tak, aby fungoval jako řídicí panel nouzového osvětlení. Pomocí fotorezistoru se bude snímat stav okolního osvětlení a měřená hodnota se zobrazí na displeji. Uživatel zadá na začátku hodnoty při kterých se zapne a naopak vypne LED připojená na D1.

Doplňkový HW:
Na vstup AIN a výstup D1 připojte dělič s fotorezistorem a LED s rezistorem podle obrázku.

Rada:

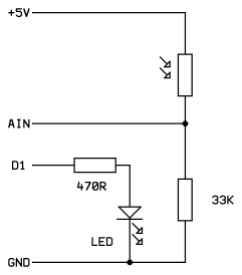
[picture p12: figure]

Použijte příkazy INPUT, PRINT, DOUT, AINP, GOTO a IF-THEN. Měřená hodnota osvětlení bude pouze číslo z A/D převodníku. Uživatel si může nastavit 2 hranice, při kterých se světlo zapne nebo vypne, a tak si nastavit hysterezi obvodu. Ošetřete, aby zadané hranice nebyly mimo rozumný rozsah.
Jako fotorezistor můžete použít typ 5537 nebo podobný.

Příklad řešení:
0 REM Nouzove osvetleni
1 PRINT “\f0\n\n“
2 INPUT H
3 IF H<10 THEN GOTO 2
4 IF H>1000 THEN GOTO 2
5 INPUT L
6 IF L>=H THEN GOTO 5
7 AINP A; CURSOR 0; PRINT A,“ “ 8 IF A<L THEN DOUT 1,1
9 IF A>H THEN DOUT 0,1
10 DELAY 200; GOTO 7

Poznámky k řešení:
Na řádcích 2 až 6 je vyžadováno zadání hranic, při kterých LED zhasne nebo se rozsvítí (i s kontrolou povolených hodnot). Vlastní smyčka je na řádcích 7 až 10. Po změření je hodnota vypsána. Příkaz PRINT je doplněn o vymazání delšího čísla, které by mohlo zůstat na displeji z předchozího měření. Pak je na řádcích 8 a 9 LED rozsvícena či zhasnuta.

Příklad 29:

Zadání:
Vytvořte z TinyBasRV jednoduchý kryptografický přístroj, který bude kódovat a dekódovat znaky abecedy a až z na jiný znak podle vámi zvolené šifrovací tabulky. Program po stisku příslušného znaku musí ukázat jak zakódovaný, tak odpovídající dekódovaný znak.

Rada:
V poli @ si pomocí příkazu LET vytvořte šifrovací tabulku. Po kontrole, zda zmáčknutá klávesa patří mezi povolené znaky, vyberte znak z tabulky, zobrazte ho a pak tabulku prohledejte pro dekódování. Doporučené příkazy PRINT, INKEY, CURSOR, GOTO a IF-THEN.

Příklad řešení:
0 REM Sifrovaci stroj
1 LET @0=6,18,11,5,20,14,22,2,9,15 2 LET @10=17,8,1,10,19,0,13,4,23,24 3 LET @20=25,7,16,12,21,3
4 PRINT “\fZnak Koder Dekoder“ 5 INKEY K
6 IF K<97 THEN GOTO 5
7 IF K>122 THEN GOTO 5
8 LET Z=K-97; CURSOR 34; PUTCH K 9 CURSOR 41; PUTCH 65+@Z; LET I=0 10 IF @I=Z THEN GOTO 12
11 LET I=I+1; IF I<26 THEN GOTO 10
12 CURSOR 50; PUTCH 65+I; GOTO 5

Poznámky k řešení:
Základem programu je kódovací tabulka v poli @. Všech 26 znaků anglické abecedy má svůj náhodně zvolený kód. Znak „a“ má kód na pozici 0, „b“ na 1, atd. Čísla kódů mohou být od 0 do 25.
Uvažujeme zadávání malých písmen abecedy, jejich hodnoty budou 97 až 122. Na to čekají řádky 5 až 7. Ukazatel do kódovací tabulky v proměnné Z získáme odečtením hodnoty 97 od znaku. Vypíšeme zadaný znak, jeho zakódovanou podobu ve formě velkého písmene, které začínají na hodnotách 65 (řádky 8 a 9). Na řádcích 10 a 11 tabulku prohledáme pro opačnou funkci – dekódování. Řádek 12 dekódovaný znak vypíše.

Příklad 30:

Zadání:
Napište program pro jednoduché stopky. První zmáčknutí libovolné klávesy měřený čas odstartuje, další pak hodnotu zastaví. Zobrazovat se bude na minuty:sekundy,desetiny sekund.

Rada:
Použijte příkazy INKEY, LET, PUTCH, PRINT, GOTO a IF-THEN. Po spuštění programu nejprve počkejte na zmáčknutí klávesy. Uložte si aktuální čas startu. Zobrazujte rozdíl mezi aktuálním časem a startem dělení 3191 (počet tiků za desetinu sekundy). Nejprve hodnotu dělenou 600 – to budou minuty a pak sekundy a desetiny sekund. Nezapomeňte, zobrazit sekundy vždy na 2 desetinná místa. Znak 0 má hodnotu 48.
Další stisk počítání zastaví, aby se dal přečíst dosažený čas. Třetí stisk klávesy pak opět vrátí stopky na nulový čas a připraví ke startu.

Příklad řešení:
0 REM Stopky
1 PUTCH 12; PRINT “0:00,0“ 2 INKEY K
3 IF K=0 THEN GOTO 2
4 TIME B
5 DELAY 80
6 TIME T; LET T=T-B; LET S=T/3191 7 LET A=S/600; LET S=S-A*600
8 CURSOR 0; PRINT A,“:“
9 LET A=S/10; LET S=S-A*10
10 IF A<10 THEN PUTCH 48
11 PRINT A,“,“,S
12 INKEY K; IF K=0 THEN GOTO 5 13 INKEY K
14 IF K=0 THEN GOTO 13
15 GOTO 1

Poznámky k řešení:
Řešení postupuje podle pokynů v odstavci Rada. Nejprve se čeká na start stopek (řádky 2 a 3). Do proměnné B se uloží čas startu. Lidské oko není příliš rychlé, tak má smyčka zobrazování zanesené zpoždění na řádku 5. Uplynulý čas v desetinách sekundy se vypočítá do proměnné S na řádku 6. Řádky 7 až 11 čas zobrazí na displej. Řádek 12 kontroluje zastavení stopek. Řádky 13 a 14 čekají na nový restart programu.

Příklad 31:

Zadání:
Napište program představující jednoduchou hru „Dostihy“. Hráč může s počátečním kapitálem vsadit částku na jednoho ze tří koní. Koně budou do cíle dobíhat s náhodným pořadím.

Rada:
Použijte např. příkazy INPUT, PRINT, PUTCH, LET, CURSOR, DELAY, TIME, GOTO a IF-THEN. Pozici, na které se nachází kůň, si uložte do pole @. Bude se pak lépe odkazovat na koně, který se bude náhodně posouvat pomocí příkazu TIME.
Při sázce na vítězného koně připočítejte hráči trojnásobek vsazené částky.

Příklad řešení:
0 REM Dostihy
1 LET M=1000
2 PRINT “\fVsadis? 1-“,M,“\n“
3 INPUT B; IF B<1 THEN GOTO 2 4 IF B>M THEN GOTO 2
5 PRINT “\nKun 1-3?\n“; INPUT K 6 LET @1=1; LET @2=1; LET @3=1 7 PRINT “\fZavod“; PUTCH p49,64
8 PUTCH p50,128; PUTCH p51,192
9 TIME T; LET V=T/3; LET V=T-V*3+1
10 DELAY 100; LET @V=@V+1; PUTCH p143,V*64+@V 11 IF @V<31 THEN GOTO 9
12 CURSOR 395; PRINT “Vyhral “,V; DELAY 1000
13 IF V=K THEN LET M=M+B*3; GOTO 2
14 LET M=M-B; IF M>0 THEN GOTO 2
15 PRINT “\nDosly prachy\n“

Poznámky k řešení:
Počáteční kapitál je nastaven na řádku 1. Pak je uživatel vyzván, aby určil hodnotu sázky s kontrolou, zda se nepokouší švindlovat (řádky 2 až 4). Řádek 5 vyzve k sázce na jednoho ze tří koňů. Zde se platnost volby nekontroluje, pokud hráč zadá nesmyslné číslo, peníze vyhodí oknem. Řádek 6 usadí koně na startovní pozici (pozice koní jsou v odpovídajícím prvku pole @). Řádky 7 a 8 připraví grafiku závodu. Na řádku 9 se vygeneruje, který kůň náhodně postoupí o jedno políčko. To je vykresleno na řádku 10 s tím, že pozice koně se uloží do jeho proměnné.
Řádek 11 řeší případné vítězství koně a ukončení závodu. Na řádcích 12 až 15 se vyplácí výhra, odebírají prohrané peníze a případně ukončuje hra při nedostatku peněz.

Příklad 32:

Zadání:
Napište pro TinyBasRV jednoduchou hru „Žabí skokani“. Na začátku budou 4 žáby jednoho druhu vlevo a 4 žáby druhého druhu vpravo. Uprostřed je jedna mezera. Hráč může skočit s libovolnou žábou do vedlejší mezery nebo jednu sousední žábu do mezery přeskočit. Cílem je na co nejmenší počet skoků přemístit žáby zleva na pravou stranu a naopak.

Rada:
Použijte příkazy INPUT, LET, PUTCH, PRINT, CURSOR, GOTO a IF-THEN. Počáteční a cílovou pozici si můžete uložit do pole @. Znaky pro žáby vlevo a vpravo si zvolte sami. Hráč bude muset vždy zadat „odkud“ skáče „kam“. Jednoduše to lze zadávat číslem např. 34 – skok z pozice 3 na 4. Budete muset ošetřit, aby hráč nezadal nesmyslné pozice skoku. Nesmí také skákat přes 2 a více žab naráz.

Příklad řešení:
0 REM Zabi skokani
1 LET P=0; LET @1=8,8,8,8,15,1,1,1,1
2 LET @10=1,1,1,1,15,8,8,8,8
3 PUTCH 12; LET I=1
4 CURSOR I*2; PUTCH v80+@I; PRINT I
5 LET I=I+1; IF I<10 THEN GOTO 4
6 PRINT “\n\n“; INPUT M; IF M>99 THEN GOTO 3 7 LET F=M/10; LET T=M-F*10; LET D=F-T
8 IF T<1 THEN GOTO 3
9 IF F<1 THEN GOTO 3
10 IF D<0 THEN LET D=-D
11 IF @T<>15 THEN GOTO 3
12 LET I=1; IF D>2 THEN GOTO 3
13 LET P=P+1; LET @T=@F; LET @F=15 14 LET K=I+9; IF @I<>@K THEN GOTO 3 15 LET I=I+1; IF I<10 THEN GOTO 14
16 PRINT “\nUspech na “,P,“ skoku“

Poznámky k řešení:
V proměnné P je uložen počet skoků. V poli jsou nejprve uloženy pozice žab při startu a pak i cílová pozice. Čísla jsou malá aby se snadno v programu zapsala. Pro zobrazení budou znaky zvýšeny o 80, takže levé žáby se objeví jako Q (81), pravé jako X (88) a volná pozice bude podtržítko (95). Na řádcích 3 až 5 je vykresleno hrací pole s žábami i s jejich pozicemi.
Na řádku 6 hráč zadá svůj skok. Ihned se kontroluje, zda číslo není moc velké. Na řádku 7 se rozdělí odkud (F) a kam (T) se skáče a jak dlouhý je to skok (D). Řádky 8 a 9 kontrolují, zda nebyla někde zadána 0 nebo záporné číslo. Řádek 10 opraví délku skoku na kladné číslo.
Řádek 11 kontroluje, jestli se skáče do volné pozice, řádek 12, není-li skok moc dlouhý. Na řádku 13 se provede platný skok. Řádky 14 a 15 zkontrolují případný konec hry při dosažení cíle.

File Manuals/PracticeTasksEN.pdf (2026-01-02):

## Tiny BASIC language exercises (ver 1)

Task 1:

Assignment:
Create a program to calculate the area of a rectangle. When the program is run, the user will be prompted to enter the lengths of the sides. Then the area will be printed. Calculate everything with integer values.

Advice:
Use the PRINT and INPUT statements. The area of a rectangle is calculated as the product of the lengths of its sides.

Solution example:
0 REM Calculate area of rectangle 1 PRINT “Enter length of sides:\n“ 2 INPUT A; INPUT B
3 PRINT “The area is: “ , A*B

Solution notes:
The program could be written on one line:
1 INPUT A; INPUT B; PRINT “The area is: “ , A*B

Rev. C

Task 2:

Assignment:
Write a program to calculate the area of a circle to 2 decimal places. When the program is run, the user is prompted to enter the radius of the circle and then the area is printed.

Advice:
Use the PRINT, LET, IF-THEN, and INPUT statements. Tiny BASIC only calculates with whole numbers. Use the value of π as 314 to calculate the area, and then display the result in sequence. First, print the whole value obtained by dividing by 100, the decimal point symbol, and then the remainder after dividing by 100. Remember that the remainder after division must be displayed with the first zero - e.g. 08.
The formula for calculating the area is known:

Solution example:
0 REM Calculate area of circle
1 PRINT “Enter radius:\n“
2 INPUT R
3 LET S=R*R*314; LET C=S/100 4 PRINT “The area is: “ , C, “.“
5 LET Z=S-C*100
6 IF Z<10 THEN PRINT “0“
7 PRINT Z

Solution notes:
Tiny BASIC does not have an operation for powers of numbers. That is why the square power is written as R*R (line 3). And it also does not work with decimal numbers. Multiplying by 314 instead of 3.14 gives a result 100 times larger. To get the whole part of the result, we must divide S by 100 (line 3). The remainder, which we calculate after subtracting the integer part multiplied by 100, must then be displayed, including any leading zero (line 6).

Task 3:

Assignment:
Create a program that prints all odd numbers up to 20.

Advice:
Use PRINT, LET, GOTO, and IF-THEN statements.

Solution example:
0 REM Odd numbers up to 20 1 LET A=1
2 PRINT A, “\n“
3 LET A=A+2
4 IF A<20 THEN GOTO 2

Solution notes:
This is a very simple counting loop. We start at 1 (line 1) and gradually print the numbers on separate lines (line 2) in increments of 2 (line 3). The evaluation condition (line 4) returns the program to print the number until 20 is reached.

Task 4:

Assignment:
Create a program that draws a rectangular triangle of the characters * 10 lines high on the screen.

Advice:
Use PUTCH, LET, GOTO, and IF-THEN statements. The newline character has the value 10 and the * character has the value 42.

Solution example:
0 REM Triangle *
1 PUTCH 10
2 LET A=1; REM Count lines 3 LET B=1; REM Stars on line 4 PUTCH 42; LET B=B+1
5 IF B<=A THEN GOTO 4
6 PUTCH 10; LET A=A+1
7 IF A<11 THEN GOTO 3

Solution notes:
There are 2 nested counting loops used here. In variable A, the lines are counted (lines 2,6,7) and in variable B, the characters printed on the line are counted (lines 3,4,5).

Task 5:

Assignment:
Create a program that draws a square with a side length of 10 characters on the screen.

Advice:
Use the PUTCH, PRINT, LET, GOTO, and IF-THEN statements. To save yourself some work, use a subroutine with GOSUB and RETURN statements to draw the horizontal line. Remember to end the program at the right point with the END statement.
The character to clear the display is 12, the new line is 10, the upper left corner is 144, the upper right corner is 145, the lower left corner is 146, the lower right corner is 147, the vertical line is 156, and the horizontal line is 157.

Solution example:
0 REM Square
1 PUTCH 12
2 LET A=1; REM Count lines 3 PUTCH 144; GOSUB 10
4 PUTCH 145; PUTCH 10
5 PUTCH 156; PRINT “ “
6 PUTCH 156; PUTCH 10; LET A=A+1 7 IF A<8 THEN GOTO 5
8 PUTCH 146; GOSUB 10
9 PUTCH 147; PUTCH 10; END
10 REM Horizontal line
11 LET I=1
12 PUTCH 157; LET I=I+1
13 IF I<9 THEN GOTO 12
14 RETURN

Solution notes:
Lines 3 and 4 draw the top of the square, lines 8 and 9 draw the bottom of the square. The subroutine on lines 10 through 14 is used to draw a horizontal line. Lines 5, 6, and 7 draw vertical lines. The number of spaces in the PRINT statement on line 5 must be 8 to empty the body of the square.

Task 6:

Assignment:
Write a program that allows you to move the character X around the screen. Starting in the middle of the screen, pressing the key 2 moves the character X down, 4 moves it left, 6 moves it right, and 8 moves it up.

Advice:
Use the PUTCH command using its parameters, CURSOR, INKEY, GOTO, and IF-THEN.
The character to clear the display has a value of 12, the X character is 88, the blank character is 32, 2 is 50, 4 is 52, 6 is 54, and 8 is 56.

Solution example:
0 REM Move X
1 PUTCH 12
2 CURSOR 400; PUTCH .88
3 INKEY K
4 IF K=50 THEN PUTCH v32; PUTCH .88 5 IF K=52 THEN PUTCH <32; PUTCH .88 6 IF K=54 THEN PUTCH >32; PUTCH .88 7 IF K=56 THEN PUTCH ^32; PUTCH .88
8 GOTO 3

Solution notes:
The program first clears the screen and places an X in the middle of the display (position 400) using the PUTCH command. The dot symbol ensures that the cursor remains at that position. When the user presses the correct key, the old position is first cleared with a blank character and the cursor moves to the new position (the direction is determined by the symbol before the value 32). The X is then printed at the new position and the cursor remains.

Task 7:

Assignment:
Create a program that will automatically "play ping-pong". A ball in the shape of the letter o will fly along a line from the left side to the right side and vice versa. It will always bounce off the edge of the screen and return.

Advice:
Use the PUTCH command using the parameters, CURSOR, DELAY, GOTO and IF-THEN.
The character to clear the display has a value of 12, the character o is 111, the blank character is 32. The position in the middle of the middle line has a value of 400, the character on the left edge 384, the right 415.

Solution example:
0 REM Ping-pong
1 PUTCH 12; LET C=400
2 CURSOR C; PUTCH .111
3 LET D=1
4 DELAY 100; PUTCH .32
5 LET C=C+D; CURSOR C; PUTCH .111 6 IF C=415 THEN LET D=-1
7 IF C=384 THEN LET D=1
8 GOTO 4

Solution notes:
First, the program is set to the initial position and the direction of the ball's movement in the variable D is set to the value 1 - i.e. the ball will fly to the right (lines 1 to 3). In the loop that starts on line 4, it waits for a while, deletes the old image of the ball and then moves the ball to a new position according to the value in D. Lines 6 and 7 monitor the edge of the screen and change the direction of flight there (D=1) or back (D=-1).

Task 8:

Assignment:
Write a program that plays a melody according to the notes in the image. At the beginning, the user enters the duration of a 1/8 note in the range 200 to 400 milliseconds.

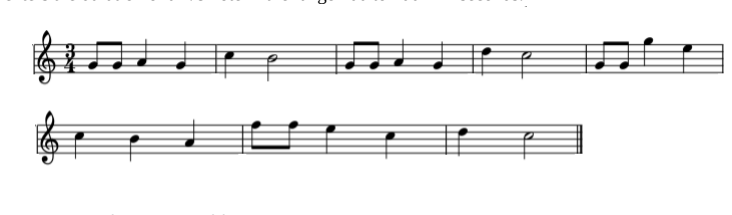
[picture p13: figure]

Approximate frequencies of fundamental tones:
c‘: 262 | d‘: 294 | e‘: 330 | f‘: 349 | g‘: 392 | a‘: 440 | h‘: 494
c“: 523 | d“: 587 | e“: 659 | f“: 698 | g“: 784 | a“: 880 | h“: 989

Advice:
Use the BEEP command with the parameters, INPUT, GOTO and IF-THEN. If the same passages appear in the melody, you can use the GOSUB and RETURN subroutines to avoid having to copy the same parts. Don't forget to end the program with the END command.

Solution example:
0 REM Melody
1 PRINT “Enter the pace:\n“ 2 INPUT T
3 IF T<200 THEN GOTO 1
4 IF T>400 THEN GOTO 1
5 GOSUB 15
6 BEEP 523,2*T; BEEP 494,4*T; GOSUB 15 7 BEEP 587,2*T; BEEP 523,4*T; BEEP 392,T 8 BEEP 392,T; BEEP 784,2*T; BEEP 659,2*T
9 BEEP 523,2*T; BEEP 494,2*T; BEEP 440,2*T 10 BEEP 698,T; BEEP 698,T; BEEP 659,2*T
11 BEEP 523,2*T; BEEP 587,2*T; BEEP 523,4*T 12 END
15 BEEP 392,T; BEEP 392,T; BEEP 440,2*T
16 BEEP 392,2*T; RETURN

Solution notes:
The user is first prompted to enter a tempo and the allowed range of values is checked (lines 1 to 4). Since the first four notes repeat in the third measure, the subroutine on lines 15 and 16 is used. The individual notes are specified by frequency and duration. A quarter note is double and a half note is quadruple the specified duration of an eighth note.

Task 9:

Assignment:
Write a program to create a very simple piano. When keys 1 to 9 are pressed, it will play the notes c' to d" for 200 to 600 milliseconds (the time is specified after the start).
Approximate frequencies of the fundamental notes:
c‘: 262 | d‘: 294 | e‘: 330 | f‘: 349 | g‘: 392 | a‘: 440 | h‘: 494
c“: 523 | d“: 587

Advice:
Use the BEEP command with the parameters, INPUT, INKEY, GOTO and IF-THEN. Try to take advantage of the fact that keys 1 to 9 return values 49 to 57 in the INKEY command. Then you can calculate the necessary jump in the GOTO command.

Solution example:
0 REM Piano
1 PRINT “Enter tone duration:\n“ 2 INPUT T
3 IF T<200 THEN GOTO 1
4 IF T>600 THEN GOTO 1
5 INKEY K
6 IF K<49 THEN GOTO 5
7 IF K>57 THEN GOTO 5
8 GOTO K-40
9 BEEP 262,T; GOTO 5
10 BEEP 294,T; GOTO 5
11 BEEP 330,T; GOTO 5
12 BEEP 349,T; GOTO 5
13 BEEP 392,T; GOTO 5
14 BEEP 440,T; GOTO 5
15 BEEP 494,T; GOTO 5
16 BEEP 523,T; GOTO 5
17 BEEP 587,T; GOTO 5

Solution notes:
The user is first prompted to enter the tone duration and the allowed range of values is checked (lines 1 to 4). In the loop that starts on line 5, it is first checked whether the key is among the allowed ones and then the jump to the line with the corresponding tone is calculated on line 8. The value of the first allowed digit 49 must go to line 9, so the value 40 is subtracted.

Task 10:

Assignment:
Create a program that will represent a lottery device for the numbers 1 to 49. Each time you press any key, it will display a random number from the specified range.

Advice:
Use the TIME, INKEY, PRINT, GOTO and IF-THEN commands.
After pressing a key, take the current time. Its remainder after dividing by 49 will be a sufficiently random number. Remember that the remainder after dividing by 49 is in the range 0 to 48. The obtained value needs to be increased by 1.

Solution example:
0 REM Lottery
1 INKEY K
2 IF K=0 THEN GOTO 1
3 TIME T; LET A=T/49
4 PRINT T-A*49+1, “\n“
5 GOTO 1

Solution notes:
Lines 1 and 2 wait for any key to be pressed. When the user presses a key, the variable T is filled with the TIME command. The value obtained by the TIME command changes approximately 32,000 times per second. Since we need random numbers up to 49, we calculate the remainder after dividing by 49. We display the result increased by 1.

Task 11:

Assignment:
Create a program that displays the time elapsed since the computer was started in the form HH:MM:SS.

Advice:
Use the TIME, PRINT, PUTCH, CURSOR, GOTO and IF-THEN commands.
If you divide the value obtained by the TIME command by 31914, you will get the time since the computer was started in seconds. Then you just need to divide the obtained time by 3600 to get the number of hours that have passed. Then divide the remainder by 60 to get the minutes. Do not forget that in Assignment the number is displayed to 2 places. It is not enough to just print out e.g. 5, it needs to be displayed as 05. A subroutine with GOSUB and RETURN can be useful for this. The character : has the value 58, the character 0 has the value 48.

Solution example:
0 REM Clock
1 PUTCH 12
2 DELAY 300
3 TIME T; LET S=T/31914
4 LET A=S/3600; LET S=S-A*3600 5 CURSOR 0; GOSUB 10
6 LET A=S/60; LET S=S-A*60
7 PUTCH 58; GOSUB 10
8 LET A=S; PUTCH 58; GOSUB 10 9 GOTO 2
10 REM List A to 2 digits
11 IF A<10 THEN PUTCH 48
12 PRINT A; RETURN

Solution notes:
We divide the time obtained by the TIME command by 31914 to get the total time in seconds. We get the hours in variable A by dividing by 3600. The remainder after integer division will be minutes and seconds. By integer division by 60 we get minutes and the remainder from the calculation of minutes is seconds. We have to display everything to 2 places, so we add any leading zero for single-digit numbers when displaying the value from A in the subroutine (line 11).

Task 12:

Assignment:
Create a “kitchen timer” using a computer. After starting the program, the user enters a time from 1 to 99 minutes. After entering, the display will start counting down in minutes and when it reaches 0, a signal will sound for 10 seconds.

Advice:
Use the TIME, BEEP, INPUT, PRINT, GOTO and IF-THEN commands. After entering the desired time, you can calculate the time at which the timing will end. The target time is obtained by adding the number of minutes multiplied by 60*31914 (seconds in a minute times the number of ticks per second = 1914840) to the current time.

Solution example:
0 REM Kitchen timer
1 PRINT “Enter time [min]:\n“ 2 INPUT T
3 IF T<1 THEN GOTO 1
4 IF T>99 THEN GOTO 1
5 TIME C; LET C=C+T*60*31914 6 PUTCH 12
7 DELAY 300
8 TIME T; LET D=C-T
9 IF D<0 THEN BEEP 800,10000; END 10 CURSOR 0; PRINT D/1914840, “ “
11 GOTO 7

Solution notes:
The user is first prompted to enter a time and the allowed range of values is checked (lines 1 to 4). After correct entry, the target time is stored in the variable C, which is calculated as the current time with the time entered by the user multiplied by 31914 (number of ticks per second) and 60 (number of seconds in a minute). In the loop that starts on line 7, we wait a while because it is not necessary to display the values so quickly that the user would not notice it anyway. On line 8, we find the difference between the target and current time. If the result is negative, we end the timing. Otherwise, we display the difference. The constant 1914840 is created by multiplying 60*31914.

Task 13:

Assignment:
Program the game "Better Perception" for two or more players. After pressing a key, it waits 5 seconds, while the timing starts *. Then it displays the target character on the display. The key that was pressed first after the target character was displayed will be declared the winner.

Advice:
Use INKEY, DELAY, PUTCH, PRINT, GOTO and IF-THEN statements. When writing your program, remember to check if the player pressed a key before displaying the target character. The * character has the value 42, the target character has the value 143.

Solution example:
0 REM Perception
1 PRINT “\nGame start\n“
2 INKEY K
3 IF K=0 THEN GOTO 2
4 PUTCH 42; DELAY 5000; INKEY K 5 PUTCH 143; IF K>0 THEN GOTO 10
6 INKEY K
7 IF K=0 THEN GOTO 6
8 PRINT “\nWinner: “; PUTCH K; DELAY 2000 9 GOTO 1
10 PRINT “\nLoser: “; PUTCH K; DELAY 2000
11 GOTO 1

Solution notes:
On lines 1 to 3 we wait for the game to start. Then we display *, wait 5 seconds, and check if someone pressed a key prematurely (line 4). On line 5 we display the target character and check for premature keypresses. If everything is OK, on lines 6 and 7 we wait for a keypress, and on line 8 we declare the winner.

Task 14:

Assignment:
Create a program for an acoustic generator. The user enters the frequency of the desired tone in the range of 100 to 4000 Hz and the computer beeps the entered tone until the program is terminated.

Advice:
Use the BEEP, INPUT, PRINT, GOTO, and IF-THEN statements.
To be able to stop the program by inserting an END statement, use some acceptable value in the time parameter of the BEEP statement in the range of seconds.

Solution example:
0 REM Audio generator
1 PRINT “Insert freq. 100-4000\n“ 2 INPUT F
3 IF F<100 THEN GOTO 1
4 IF F>4000 THEN GOTO 1
5 BEEP F,5000
6 GOTO 5

Solution notes:
The user is first prompted to enter a frequency and the allowed range of values is checked (lines 1 to 4). Then, a tone of the specified frequency is played continuously in a loop on lines 5 and 6.

Task 15:

Assignment:
Write a program in which the user enters a name followed by the Enter key. The computer then prints out that the name is his friend. The maximum length of the name can be 30 characters.

Advice:
Use the INKEY, PRINT, PUTCH, GOTO and IF-THEN commands. It is convenient to store the entered name in variables in the @ array. Count the number of letters stored.

Solution example:
0 REM Computer friend
1 LET I=0; PRINT “\nEnter name:\n“ 2 INKEY K
3 IF K=0 THEN GOTO 2
4 IF K=10 THEN GOTO 10
5 PUTCH K; LET @I=K; LET I=I+1 6 IF I=30 THEN GOTO 10
7 GOTO 2
10 LET J=0; PUTCH 10
11 PUTCH @J; LET J=J+1
12 IF J<I THEN GOTO 11
13 PRINT “ is my friend\n“

Solution notes:
Lines 2 and 3 wait for a character to be entered. Line 4 checks whether the input was terminated by pressing the Enter key. Line 5 stores the character in the array. Line 6 checks the maximum allowed length of the name. Lines 10 to 12 print the name again.

Task 16:

Assignment:
Create a program to control an LED connected to output D1 using the keyboard. The first press of any key turns the LED on, the second press turns it off, the next press turns it on again, and so on.

Additional HW:
Connect an LED with a resistor to the D1 output as shown in the following figure. The red LED will be suitable for the following task.

Advice:


Use the INKEY, DOUT, GOTO, and IF-THEN statements. The DOUT 1,1 statement turns the LED on, and the DOUT 0,1 statement turns it off.
Since the program doesn't have to be fast, you can insert a small delay into the keypress cycle with the DELAY statement.

Solution example:
0 REM LED control
1 LET L=0
2 DELAY 100; INKEY K
3 IF K=0 THEN GOTO 2
4 IF L=0 THEN GOTO 6
5 LET L=0; DOUT 0,1; GOTO 2
6 LET L=1; DOUT 1,1; GOTO 2

Solution notes:
The variable L stores the current value of the output so that we know how to change the output next time. Lines 2 and 3 wait for a key press. Line 4 decides whether the LED turns on or off based on the state of L.

Task 17:

Assignment:
Create a program that turns TinyBasRV into a control for warning lights at a railroad crossing, including sound signaling.

Additional HW:
Connect two LEDs (preferably red) with resistors to outputs D1 and D2 as shown in the following figure.

Advice:

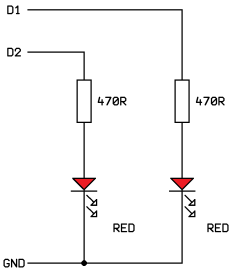
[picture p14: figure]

Use the BEEP, DELAY, DOUT and GOTO commands. Try out the sound signaling and adjust it to your liking.

Solution example:
0 REM Railroad crossing
1 DOUT 1,1; DOUT 0,2
2 BEEP 2000,100; BEEP 800,200; DELAY 200 3 DOUT 0,1; DOUT 1,2
4 BEEP 2000,100; BEEP 800,200; DELAY 200
5 GOTO 1

Solution notes:
Lines 1 and 3 always light up only one of the two LEDs. Lines 2 and 4 generate the same sound signal. The example given only very vaguely resembles the ringing of a bell. You can tune and adjust them to your ear...

Task 18:

Assignment:
Create a program to measure the input voltage at the AIN input in mV. Apply the voltage from the potentiometer slider to the input, which will be displayed with a period of ½ second.

Additional HW:
Connect a linear potentiometer with a resistance value in the range of 1 to 100 kΩ to the AIN output according to the following figure.

Advice:


Use the AINP, DELAY, CURSOR, PRINT, and GOTO commands. The value obtained from the A/ D converter is in the range 0 to 1023. This represents a voltage of 0 to 5V – that is, 0 to 5000 mV. To convert the A/D converter range to mV, we must first multiply the value by 5000 and then divide by 1023.

Solution example:
0 REM Analog input mV
1 PUTCH 12
2 CURSOR 397; AINP A
3 PRINT A*5000/1023, “ mV “ 4 DELAY 500
5 GOTO 2

Solution notes:
On line 2, first set the cursor approximately to the center of the screen and then measure the voltage at the AIN input. The conversion is performed when the value is printed in the PRINT command according to the instructions in the Advice paragraph. After the units are printed, 3 spaces are added to erase any longer entries from the previous measurement.

Task 19:

Assignment:
Modify the TinyBasRV computer to work as a simple voltmeter with a range of up to 50 V. The voltage will be displayed with a period of ½ second and a resolution of 2 decimal places.

Additional HW:
Connect an input resistor divider to the AIN output with resistors with a resistance ratio of 9:1. For example, 900 kΩ and 100 kΩ would be ideal. However, the value of 900 kΩ is outside the normal range of available resistors. You can use the closest value of 910 kΩ from the E24 series. In an emergency, you can also use 1 MΩ and adjust the constant in the program.

Advice:


Use the AINP, DELAY, CURSOR, PUTCH, PRINT, GOTO, and IF-THEN commands. The value obtained by AINP from the A/D converter is in the range of 0 to 1023. This represents a voltage of 0 to 50V (we need to display 0.00 to 50.00 V). To convert the A/D converter range to V, we first need to multiply the value by 5000 and then divide by 1023. We display the resulting number with a decimal point between the digits.
The multiplication constant of 5000 is the ideal case, when an accurate reference voltage in the microcontroller and accurate resistance values of the two resistors in the divider are assumed. In practice, this will vary. Therefore, for a particular piece of computer, this value needs to be adjusted so that the displayed voltage is as close as possible to the voltage measured by the reference voltmeter.

Solution example:
0 REM Voltmeter 50V
1 PUTCH 12; LET K=5320
2 CURSOR 397; AINP A
3 LET V=A*K/1023; LET C=V/100 4 LET Z=V-C*100
5 PRINT C, “.“
6 IF Z<10 THEN PRINT “0“
7 PRINT Z
8 DELAY 500
9 GOTO 2

Solution notes:
Line 1 sets the conversion constant, which you must adjust according to the specific computer and input resistor divider. The next step copies the instructions given in the Advice paragraph. First, the entire part of the variable C is printed, and then the remainder after dividing 100 from Z. If the remainder is less than 10, it is necessary to add a leading zero (line 6).

Task 20:

Assignment:
Using a PCF8575 expander connected to a TinyBasRV, make a running light on a series of LEDs connected to the expander outputs.

Additional HW:
Connect multiple LEDs to the outputs of the PSC8575 expander module as shown in the picture. It depends on the number of LEDs you have available, a maximum of 16 LEDs can be connected.

Advice:


Use the I2CW, DELAY, LET, GOTO and IF-THEN commands. To light the first LED, you need to send the binary number b1111111111111110 or decimal -2 to the expander. The second LED requires sending the binary number b1111111111111101 or decimal -3. The next would be the binary number b1111111111111011 or decimal -5. The LED lighting is moved to the next position by multiplying by 2 and adding 1.
After the last LED is lit, the light must return to the beginning.

Solution example (for 8 LEDs): 0 REM Running 8 LED
1 LET A=-2
2 I2CW A; DELAY 200
3 LET A=A*2+1
4 IF A < -300 THEN LET A=-2
5 GOTO 2

Solution notes:
The program follows the instructions given in the Advice paragraph. In the given example, only 8 LEDs were used, when reaching a value less than -300 the value in A returns to the beginning. Sending the number -257 to the expander (the last one sent in the cycle) will turn off all 8 LEDs for a while. If you do not want this, reduce the condition, for example, to A<-150.

Task 21:

Assignment:
Write a program that uses a PCF8575 expander connected to TinyBasRV to light up a specified number of LEDs (an image of your choice) when you press the 0 to 9 key.

Additional HW:
Connect multiple LEDs to the outputs of the PSC8575 expander module as shown in the picture. It depends on the number of LEDs you have available, a maximum of 16 LEDs can be connected.

Advice:

Use the I2CW, DELAY, INKEY, GOTO and IF-THEN commands. You can specify any pattern of LED lights for each digit. For example, pressing key 1 will light up each odd LED with the I2CW command b1010101010101010, key 2 will light up the bottom half of the LEDs with the I2CW command b111111100000000, etc.
Keys 0 to 9 return values 48 to 57 in the INKEY command.

Solution example:
0 REM LED patterns
1 DELAY 100; INKEY K
2 IF K<48 THEN GOTO 1
3 IF K>57 THEN GOTO 1
4 GOTO K-43
5 I2CW b1100110011001100; GOTO 1 6 I2CW b1010101010101010; GOTO 1 7 I2CW b1111111100000000; GOTO 1 8 I2CW b1111100001100101; GOTO 1 9 I2CW b0000000011001100; GOTO 1 10 I2CW b1100110000000000; GOTO 1 11 I2CW b1110111011101110; GOTO 1 12 I2CW b1101110111011101; GOTO 1 13 I2CW b1011101110111011; GOTO 1
14 I2CW b0111011101110111; GOTO 1

Solution notes:
First, lines 1, 2, and 3 ensure that only the allowed number keys are accepted. Line 4 then ensures a jump to the appropriate pattern of lit LEDs and a return to the beginning.

Task 22:

Assignment:
Program a user's perception meter. After pressing a key, the program waits a random number of seconds (1 to 10), with the timing starting at *. Then it displays the target character on the display. The user must press any key as quickly as possible. The display shows the reaction time in milliseconds.

Advice:
Use the INKEY, TIME, DELAY, PUTCH, PRINT, GOTO, and IF-THEN commands. When writing your program, remember to check to see if the player pressed a key before the target character is displayed. To measure time in milliseconds, we will assume that TIME returns a value 32 larger for each millisecond.
The * character has the value 42, the target character has the value 143.

Solution example:
0 REM Perception meter
1 PRINT “\nStart\n“
2 INKEY K
3 IF K=0 THEN GOTO 2
4 TIME T; LET C=T/10
5 LET D=T-C*10+1; LET D=D*1000 6 PUTCH 42; DELAY D
7 INKEY K; PUTCH 143; TIME S 8 IF K>0 THEN GOTO 14
9 INKEY K
10 IF K=0 THEN GOTO 9
11 TIME E; LET R=E-S
12 PRINT “\nReaction: “, R/32 13 PRINT “ milisec“; GOTO 1 14 PRINT “\nPrematurely!“
15 GOTO 1

Solution notes:
Lines 2 and 3 wait for the measurement to start. Then, using the TIME command and the remainder after dividing by 10, a random time is obtained, which is stored in the variable D in milliseconds (lines 4 and 5). Line 6 displays * and waits. Line 7 reads the key state, displays the target character, and stores the starting time for the perception measurement. Line 8 checks for any premature key presses. Lines 9 and 10 wait for the user to respond. The time at which the user responded is stored in E, and then lines 11, 12, and 13 print the result.

Task 23:

Assignment:
If you have the choice to connect a dot matrix printer with a parallel port to the TinyBasRV via a PCF8575 expander, create a simple typewriter from it.

Additional HW:
Connect the Cannon 25 female connector to the outputs of the PCF8575 expander module as shown in the picture.

Advice:


Use the I2CW, DELAY, INKEY, GOTO and BEEP commands. The BEEP command is used to sound a short beep when a key is pressed. It is not necessary to use it.
On pin 1 of the parallel port there is a STROBE signal controlled by output P10, which confirms and writes data to the printer. The active value is logical 0. After writing the data, it is necessary to return this signal to the idle value 1. This is easiest to do by writing a value 256 greater than the data being written.

Solution example:
0 REM Typewriter
1 INKEY K
2 IF K=0 THEN GOTO 1
3 I2CW K; PUTCH K
4 DELAY 10
5 I2CW K+256; BEEP 1000,50
6 GOTO 1

Solution notes:
Lines 1 and 2 wait for a keystroke. Line 3 sends the character to the printer and copies it to the display. Line 4 waits for a moment (in case the printer is slow to respond). Line 5 must set the STROBE signal for the printer back to logic 1 (the character value is increased by the 9th bit set to
1) and a short beep is emitted.

Task 24:

Assignment:
Create a simple integer calculator from TinyBasRV. The user enters the first number, then the operand (+ - * /) and finally the second number. The calculated result appears on the display in the form, for example, 256*2=512.

Advice:
Use the INPUT, INKEY, PRINT, PUTCH, GOTO, and IF-THEN commands. The operand characters have the following values:
+ | 43 | - | 45 | * | 42 | / | 47
Don't forget that we don't divide by zero!

Solution example:
0 REM Calculator
1 PUTCH 10; INPUT A
2 INKEY K
3 IF K=42 THEN GOTO 8
4 IF K=43 THEN GOTO 8
5 IF K=45 THEN GOTO 8
6 IF K=47 THEN GOTO 8
7 GOTO 2
8 PUTCH K; PUTCH 10; INPUT B;
9 PRINT A; PUTCH K; PRINT B
10 IF K=43 THEN PRINT “=“,A+B; GOTO 1
11 IF K=45 THEN PRINT “=“,A-B; GOTO 1
12 IF K=42 THEN PRINT “=“,A*B; GOTO 1
13 IF B=0 THEN PRINT “0 not possible!“; GOTO 1
14 PRINT “=“,A/B; GOTO 1

Solution notes:
The first value is stored in variable A on line 1. Then lines 3 through 7 wait for the operation type. Line 8 prints the operation character and waits for the second value. Lines 10 through 14 perform the calculation based on the state of K, with line 13 checking for division by 0.

Task 25:

Assignment:
Write a program to guess a secret number from 0 to 99. After starting, the computer chooses a random number and the player has to guess this number in the fewest number of attempts possible. After each attempt, the computer indicates whether the secret number is greater or less than the one entered by the player.

Advice:
Use the INPUT, PRINT, TIME, LET, GOTO, and IF-THEN statements. First, generate a random number using the TIME statement and the remainder after dividing by 100.

Solution example:
0 REM Guess number
1 TIME T; LET C=T/100; LET X=T-C*100 2 LET P=0; PRINT “\nGuess number\n“ 3 INPUT A; LET P=P+1
4 IF A=X THEN GOTO 8
5 IF A>X THEN GOTO 7
6 PRINT P,“. Guess more\n“; GOTO 3 7 PRINT P,“. Guess less\n“; GOTO 3
8 PRINT “You guessed in “, P, “ tries\n“

Solution notes:
On line 1, a randomly generated guessed number is stored in variable X using the TIME command and the remainder after integer division by 100. On lines 2 and 3, the user is asked to try to guess the number, and the number of attempts is counted in variable P. Lines 4 and 5 check the success of the attempt, and the remaining lines print instructions on where to go for the next guess or exit the program with the result.

Task 26:

Assignment:
Create a simple code lock from TinyBasRV. If the user enters the correct sequence of 4 or 5 digits on the keyboard, a logical 1 will appear on the D1 output for 3 seconds and a sound signal will sound.

Advice:
Use the INKEY, LET, DOUT, BEEP, GOTO and IF-THEN commands. You can choose the number of code digits yourself. Store the secret number combination in the @ array and each correctly guessed digit will move the pointer in the array to a higher value. If you make a mistake, the pointer will return to the beginning of the array.
The keys 0 to 9 return the values 48 to 57 in the INKEY command.

Solution example:
0 REM Code lock
1 LET @0=49,57,50,48,51
2 LET P=0
3 INKEY K
4 IF K=0 THEN GOTO 3
5 IF K<>@P THEN GOTO 2
6 LET P=P+1;
7 IF P<5 THEN GOTO 3
8 DOUT 1,1; BEEP 800,3000; DOUT 0,1
9 GOTO 2

Solution notes:
On line 1, the lock code is stored in the @ array. The variable P shows where the user got to when entering the code. Line 5 decides whether to advance to the next position or return to the first digit of the code. On line 7, if the procedure is correct and the P pointer reaches the value 5, it is possible to move to line 8, where the code lock opens for 3 seconds.

Task 27:

Assignment:
Write a program that will replace a dice. The program will display the points on the screen as they are located on the dice.

Advice:
If you look at the patterns on the sides of the cube, you will notice that, except for the center dot, the dots always appear in pairs. For example, 3 is a combination of A+B, 5 is A+B+C.


You can encode patterns into an array, for example using binary numbers, and then display them according to a randomly drawn number. Recommended cursor positions are for A: 400, for B: 235 and 565, for C: 245 and 555, and for D: 395 and 405. Use the LET, TIME, INKEY, GOTO, CURSOR, PUTCH, and IF-THEN commands.

Solution example:
0 REM Dice
1 PUTCH 12; LET @0=1,2,3,6,7,14
2 INKEY K
3 IF K=0 THEN GOTO 2
4 TIME D; LET C=D/6; LET D=D-C*6
5 CURSOR 400; PUTCH .32; IF @D&1 THEN PUTCH 143 6 CURSOR 235; PUTCH 32; CURSOR 565
7 PUTCH .32; IF@D&2 THEN PUTCH 143
8 CURSOR 235; IF@D&2 THEN PUTCH 143
9 CURSOR 245; PUTCH 32; CURSOR 555 10 PUTCH .32; IF@D&4 THEN PUTCH 143 11 CURSOR 245; IF@D&4 THEN PUTCH 143 12 CURSOR 395; PUTCH 32; CURSOR 405 13 PUTCH .32; IF@D&8 THEN PUTCH 143 14 CURSOR 395; IF@D&8 THEN PUTCH 143
15 GOTO 2

Solution notes:
The @ array encodes the display of the numbers 0 to 5 using binary code. If you look at how the numbers are written in binary, you will see that the lowest bit represents dot A, the next higher bit represents both dots B, the next C, and the fourth bit is dot D. Lines 2 and 3 wait for a key to be pressed. Line 4 generates a random number 0 to 5 in variable D. Then all positions of the individual dots are traversed. For example, in line 5, the cursor is set to dot A and it is deleted first. If the array element with index D has the lowest bit set, the dot at the position is drawn.

Task 28:

Assignment:
Complete the TinyBasRV to function as an emergency lighting control panel. The photoresistor will be used to sense the ambient light level and the measured value will be displayed on the display. The user will initially enter the values at which the LED connected to D1 will turn on and off.

Additional HW:
Connect a divider with a photoresistor and an LED with a resistor to the AIN input and D1 output as shown in the figure.

Advice:

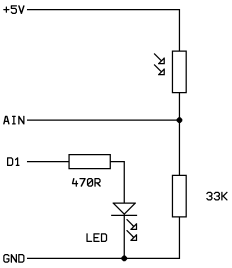
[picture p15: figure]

Use the INPUT, PRINT, DOUT, AINP, GOTO and IF-THEN commands. The measured light value will be just a number from the A/D converter. The user can set 2 limits at which the light turns on or off, thus setting the hysteresis of the circuit. Make sure that the entered limits are not outside a reasonable range.
You can use a type 5537 or similar as a photoresistor.

Solution example:
0 REM Emergency lighting
1 PRINT “\f0\n\n“
2 INPUT H
3 IF H<10 THEN GOTO 2
4 IF H>1000 THEN GOTO 2
5 INPUT L
6 IF L>=H THEN GOTO 5
7 AINP A; CURSOR 0; PRINT A,“ “ 8 IF A<L THEN DOUT 1,1
9 IF A>H THEN DOUT 0,1
10 DELAY 200; GOTO 7

Solution notes:
Lines 2 to 6 require the entry of the limits at which the LED turns off or on (including checking the allowed values). The actual loop is on lines 7 to 10. After the measurement, the value is printed. The PRINT command is supplemented by deleting a longer number that could remain on the display from the previous measurement. Then, on lines 8 and 9, the LED is turned on or off.

Task 29:

Assignment:
Create a simple cryptographic device from TinyBasRV that will encode and decode characters from the alphabet to another character according to your chosen encryption table. The program must display both the encoded and the corresponding decoded character after pressing character on keyboard.

Advice:
Use the LET command to create an encryption table in the @ array. After checking whether the pressed key is among the allowed characters, select a character from the table, display it, and then search the table for decoding. Recommended commands are PRINT, INKEY, CURSOR, GOTO, and IF-THEN.

Solution example:
0 REM Cryptograph
1 LET @0=6,18,11,5,20,14,22,2,9,15 2 LET @10=17,8,1,10,19,0,13,4,23,24 3 LET @20=25,7,16,12,21,3
4 PRINT “\fChar Coder Decoder“ 5 INKEY K
6 IF K<97 THEN GOTO 5
7 IF K>122 THEN GOTO 5
8 LET Z=K-97; CURSOR 34; PUTCH K 9 CURSOR 41; PUTCH 65+@Z; LET I=0 10 IF @I=Z THEN GOTO 12
11 LET I=I+1; IF I<26 THEN GOTO 10
12 CURSOR 50; PUTCH 65+I; GOTO 5

Solution notes:
The basis of the program is the encoding table in the @ array. All 26 characters of the English alphabet have their randomly chosen code. The character "a" has a code at position 0, "b" at 1, etc. The code numbers can be from 0 to 25.
We consider entering lowercase letters of the alphabet, their values will be 97 to 122. Lines 5 to 7 are waiting for this. We obtain a pointer to the encoding table in the variable Z by subtracting the value 97 from the character. We print the entered character, its encoded form in the form of an uppercase letter, which begin with the values 65 (lines 8 and 9). On lines 10 and 11 we search the table for the opposite function - decoding. Line 12 prints the decoded character.

Task 30:

Assignment:
Write a program for a simple stopwatch. The first press of any key will start the measured time, the next press will stop the value. It will be displayed in minutes:seconds,tenths of seconds.

Advice:
Use the INKEY, LET, PUTCH, PRINT, GOTO and IF-THEN commands. After starting the program, first wait for a key press. Save the current start time. Display the difference between the current time and the start time by dividing 3191 (the number of ticks per tenth of a second). First, the value divided by 600 – these will be minutes, then seconds and tenths of seconds. Remember to always display seconds to 2 decimal places. The character 0 has the value 48.
Another press stops the counting so that the time reached can be read. A third press of the key then returns the stopwatch to zero time and prepares it for starting.

Solution example:
0 REM Stopwatch
1 PUTCH 12; PRINT “0:00,0“ 2 INKEY K
3 IF K=0 THEN GOTO 2
4 TIME B
5 DELAY 80
6 TIME T; LET T=T-B; LET S=T/3191 7 LET A=S/600; LET S=S-A*600
8 CURSOR 0; PRINT A,“:“
9 LET A=S/10; LET S=S-A*10
10 IF A<10 THEN PUTCH 48
11 PRINT A,“,“,S
12 INKEY K; IF K=0 THEN GOTO 5 13 INKEY K
14 IF K=0 THEN GOTO 13
15 GOTO 1

Solution notes:
The solution follows the instructions in the Advice paragraph. First, the stopwatch is waited for to start (lines 2 and 3). The start time is stored in variable B. The human eye is not very fast, so the display loop has a delay on line 5. The elapsed time in tenths of a second is calculated in variable S on line 6. Lines 7 to 11 display the time on the display. Line 12 checks to see if the stopwatch has stopped. Lines 13 and 14 wait for the program to restart.

Task 31:

Assignment:
Write a program that represents a simple game called "Horse Racing". The player can bet an amount on one of three horses with an initial capital. The horses will finish in a random order.

Advice:
Use, for example, the commands INPUT, PRINT, PUTCH, LET, CURSOR, DELAY, TIME, GOTO and IF-THEN. Store the position of the horse in the @ array. This will make it easier to refer to the horse, which will be moved randomly using the TIME command.
When betting on the winning horse, add three times the bet to the player.

Solution example:
0 REM Horse Racing
1 LET M=1000
2 PRINT “\fBet? 1-“,M,“\n“
3 INPUT B; IF B<1 THEN GOTO 2 4 IF B>M THEN GOTO 2
5 PRINT “\nHorse 1-3?\n“; INPUT K 6 LET @1=1; LET @2=1; LET @3=1 7 PRINT “\fRace“; PUTCH p49,64
8 PUTCH p50,128; PUTCH p51,192
9 TIME T; LET V=T/3; LET V=T-V*3+1
10 DELAY 100; LET @V=@V+1; PUTCH p143,V*64+@V 11 IF @V<31 THEN GOTO 9
12 CURSOR 395; PRINT “Win “,V; DELAY 1000
13 IF V=K THEN LET M=M+B*3; GOTO 2
14 LET M=M-B; IF M>0 THEN GOTO 2
15 PRINT “\nNo money\n“

Solution notes:
The initial capital is set on line 1. Then the user is asked to determine the value of the bet with a check to see if he is trying to cheat (lines 2 to 4). Line 5 asks to bet on one of the three horses. Here, the validity of the choice is not checked; if the player enters a meaningless number, the money is thrown out the window.
Line 6 places the horse in the starting position (the horse positions are in the corresponding element of the array @). Lines 7 and 8 prepare the race graphics. Line 9 generates which horse will randomly advance one space. This is plotted on line 10, with the horse's position being stored in its variable.
Line 11 handles the eventual victory of the horse and the end of the race. Lines 12 to 15 pay out the winnings, collect the lost money, and eventually end the game if there is a shortage of money.

Task 32:

Assignment:
Write a simple game for TinyBasRV called "Frog Jumpers". At the beginning, there will be 4 frogs of one type on the left and 4 frogs of another type on the right. There is one gap in the middle. The player can jump with any frog into the adjacent gap or jump over one of the neighboring frogs into the gap. The goal is to move the frogs from the left to the right side and vice versa in the fewest number of jumps.

Advice:
Use the INPUT, LET, PUTCH, PRINT, CURSOR, GOTO and IF-THEN commands. You can store the starting and target positions in the @ array. Choose the characters for the frogs on the left and right yourself. The player will always have to enter "from where" frog jumps "to where". This can be simply entered as a number, e.g. 34 - jump from position 3 to 4. You will have to take care that the player does not enter meaningless jump positions. They are also not allowed to jump over 2 or more frogs at once.

Solution example:
0 REM Frog Jumpers
1 LET P=0; LET @1=8,8,8,8,15,1,1,1,1
2 LET @10=1,1,1,1,15,8,8,8,8
3 PUTCH 12; LET I=1
4 CURSOR I*2; PUTCH v80+@I; PRINT I
5 LET I=I+1; IF I<10 THEN GOTO 4
6 PRINT “\n\n“; INPUT M; IF M>99 THEN GOTO 3 7 LET F=M/10; LET T=M-F*10; LET D=F-T
8 IF T<1 THEN GOTO 3
9 IF F<1 THEN GOTO 3
10 IF D<0 THEN LET D=-D
11 IF @T<>15 THEN GOTO 3
12 LET I=1; IF D>2 THEN GOTO 3
13 LET P=P+1; LET @T=@F; LET @F=15 14 LET K=I+9; IF @I<>@K THEN GOTO 3 15 LET I=I+1; IF I<10 THEN GOTO 14
16 PRINT “\nDone in “,P,“ jumps“

Solution notes:
The number of jumps is stored in the variable P. The @ first stores the frogs' starting positions and then the target position. The numbers are small to make them easy to write in the program. For display, the characters will be increased by 80, so that the left frogs will appear as Q (81), the right as X (88), and the free position will be an underscore (95). Lines 3 to 5 draw the playing field with the frogs and their positions.
On line 6, the player enters his jump. It is immediately checked whether the number is not too large. On line 7, it is divided into from (F) and to (T) the jump is made and how long the jump is (D). Lines 8 and 9 check whether a 0 or negative number has been entered somewhere. Line 10 corrects the jump length to a positive number.
Line 11 checks whether the jump is made to a free position, line 12 if the jump is not too long. A valid jump is made on line 13. Lines 14 and 15 check for a possible game end when the goal is reached.

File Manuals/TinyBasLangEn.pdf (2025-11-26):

# Tiny BASIC

# for

# TinyBasRV

Rev C | 1

## Software ver. 1.0

The TinyBasRV microcomputer contains a Tiny BASIC language interpreter with some limitations and, conversely, with a number of improvements. The interpreter provides the user interface (communication with the user) and also execution of the stored program.
After turning on the microcomputer, the message "Tiny BASIC x.x" appears on the VGA display indicating the current version of the interpreter. This document should have the same version as reported by the computer after starting. The microcomputer simultaneously tests the available hardware and possibly reports that the DISK f and the PCF8575 expander on the I2C bus are not available and that some functions are limited. To connect the "f" disk or expander, follow the instructions "What to do when..." at the end of this manual.

When interacting with the user, the microcomputer expects a command to be entered at the prompt in two possible formats:
STATEMENT (; STATEMENT) (; STATEMENT)
or
NUM STATEMENT (; STATEMENT) (; STATEMENT)
where STATEMENT represents a Tiny BASIC command that can be executed. If a line begins with a statement, it is executed immediately. If a line begins with a number NUM (in the range 0 to 127), the statement is not executed, but is stored in memory and becomes one of the lines of the program waiting to be executed.

Example:
PRINT 5+46
It immediately prints the result on the line 51
On the contrary
26 PRINT 5+46
does nothing. This line is stored at line number 26 in the program memory in the current "file" (see the FILE command). It remains inactively written in memory until the program is run. Only after the program is run is the command executed at the moment when line number 26 is processed.

There can be one, two, or three semicolon-separated statements on a line, which are executed sequentially from the left. Some statements, such as REM, GOTO, IF, cause the next statement (or statements) on the line to not be executed.

### Writing a program

The program or interpreter commands are entered using the keyboard on the line at the blinking cursor. Printable characters appear on the screen immediately after entry. If you need to enter more than one "space" character, you can use the Tab key, which expands to 4 spaces. Any errors can be undone with the "Back Space" key. Moving on the line using the arrows is not possible, you can only delete characters one by one.
You can delete a misspelled line by entering a blank line. At the beginning of the line, type only the number of the deleted line and then press Enter. The misspelled line is corrected automatically after you type a new correct version of the line.
Tiny BASIC language commands are not written out character by character, but are entered by pressing 2 keys simultaneously. Commands are entered by pressing one key while simultaneously holding down the "Left CTRL" key. The list of allowed commands and their corresponding keys is in the summary table on the last page of this document.
Commands (STATEMENT) can be entered up to 3 at the same line. Most commands expect one or more parameters in a specific, precisely defined format after the command itself. The list of parameters and their meaning is given below in the description of individual commands and also in the table on the last page. The main parameters of the commands are:

STRING
is a text string enclosed in quotation marks. Any printable characters can be included within the string. A special case within a string is the combination of two characters - "\" (backslash) followed by the letters "n", "t" or "f" - e.g. "\n". These combinations cause:
n- line break
t - tab with cursor movement to positions divisible by 8 (i.e. 0,8,16,24)
f - clear the screen and return the cursor to the top left

VAR
indicates a variable in which numerical values are stored. Since a 32-bit computer is used, all variables are also 32-bit. The values stored in them can be in the range -2,147,483,648 to 2,147,483,647. The user has a total of 126 automatically predefined variables. These are divided into two groups. Either they have their own name and are indicated by uppercase letters of the English alphabet A to Z (26 variables in total).
Or they form an indexed array of 100 items. The array can be accessed using the "@" character, immediately followed by the index number of the item given by one or two digits, or a letter indicating the variable where the index value is stored.

Examples of allowed variable names: A, .. Q, .. Z
Examples of array element names: @0, .. @9, .. @10, .. @28, .. @99, @A .. @Z.

Direct indexing of an array by digits does not exceed the array size, because the interpreter processes only one or two digits. However, if a variable is used for indexing, its contents may exceed the size of the array. For example, if A contains the value 4786, then a reference to an array element @A will cause an error message and the program to terminate.

EXPR
represents a mathematical expression with a computable value. It can be a number, the content stored in a variable, or an algebraic expression for calculating a specific value. The usable forms of expressions are described in the mathematics of the language below.

NUM
a number entered directly using consecutive decimal digits. The second option is to enter the number in binary form. A binary number is indicated by the letter "b" followed closely by the digits 0 or 1.

### Mathematics of language

The language uses integer arithmetic, so it is not possible to enter numbers with fractional part. The range of a number can be from -2147483648 to 2147483647. Numbers outside this range will not be processed correctly.
Calculations process 32-bit numbers in the specified range. Addition, subtraction, multiplication and division operations can be used for calculations. The priority of operations (multiplication and division have priority over addition and subtraction) is respected. With the same priority level, expressions are processed from left to right.
Mathematics can be written formally:

EXPR = ( |+|-)TERM ((+|-) TERM)^
where TERM = FACT ((*|/) FACT)^
and FACT = VAR | NUM ...... see above.

Items in parentheses are optional. Options are separated by the character "|". Parentheses marked "^" can be repeated until the end of the line.
Examples of mathematical expressions (EXPR) that are allowed:
| -5 A/3 + @23 10 + A*15 - @G/42*R -114783648 – Q * R* S* T + 526 / C

Parentheses cannot be used in mathematics in the program. If we need to calculate, for example, the formula A=(B+C)/(D-E), it is necessary to divide the calculation into several steps - for example:

| LET F=B+C; LET G=D-E; LET A=F/G

### Commands

The same formal description was used when entering the parameters of individual commands as the description given above for the language mathematics. Items in parentheses are optional and brackets marked "^" can be repeated until the end of the line.

Command: PRINT
Parameters: (STRING | EXPR) (,(STRING | EXPR))^
Command function: Prints the data specified in the parameters to the screen from the current cursor position. STRING is printed in text form without leading and closing quotation marks. EXPR is printed as a number expressed by the given mathematical expression.

Examples:
PRINT 5+3 | prints the number 8 at the current screen position
PRINT "Result is " , B | prints according to the content of B e.g. Result is 115
PRINT A, "\n", B, "\n", C | will print the contents of variables A,B,C one after the other on
| the lines below them

Command: IF
Parameters: EXPR RelOp EXPR
Command function: This statement is closely related to the following THEN statement, which must immediately follow on the same line. They form a single, linked pair of statements, effectively representing a single double statement.

Command: THEN
Parameters: STATEMENT
Command function: Together with the IF statement, they create a decision condition that allows for conditional processing of another statement or branching of the program. The IF-THEN pair executes the STATEMENT statement in the THEN parameter only if the relational condition EXPR RelOp EXPR in the parameter of the IF statement is true.
RelOp is a comparison condition between two EXPR expressions. It can be of the form:
= | are both expressions the same?
< | is the first expression less than the second?
<> | are the expressions different?
<= | is the first expression less than or equal to the second?
> | is the first expression greater than the second?
>< | are the expressions different?
>= | is the first expression greater than or equal to the second?
& | is the bitwise logical conjunction of the expressions non-zero?
If the condition is true, the STATEMENT command is executed, otherwise, the command is not executed.
Attention! If the condition is false, the execution of the line after the THEN keyword is not continued and the program moves to the next line of the program. This property can be used when executing multiple commands simultaneously. If the condition is met, the execution of the line continues and since there can be up to 3 commands on a line, it is possible to execute or not execute up to 3 commands after evaluating one condition.
Examples:
IF A>5 THEN PRINT A | the content of A is only printed if it is greater than 5

IF A*5=100 THEN GOTO 35 | if the value in A is 20, the program jumps to line 35,
| otherwise it continues with the next line
IF C&b1000 THEN BEEP 1000,100 | if bit no. 3 in variable C is log. 1, a tone will sound
IF A=0 THEN LET A=1; PRINT B | if the value of A is zero, A changes to 1 and B is printed

Command: GOTO
Parameters: EXPR
Command function: This is a jump function that transfers the current position of the processed lines to the line whose number is given by the expression EXPR. The command is only meaningful in the processing mode of a running program. If the user enters it as a command in the command entry mode, nothing is done. The command parameter is a general expression. However, the programmer must ensure that the value of this expression does not exceed the range 0 to 127. If an attempt is made to "jump" outside the allowed line number, an error is reported and program execution stops.

Examples:
GOTO 23 | transfers program execution to line number 23
GOTO 10+I*5 | according to the value in variable I, the program jumps to a line in
| multiples of 5

Command: INPUT
Parameters: VAR (,VAR)^
Command function: Entering numerical values into individual variables. The programmer can choose as a parameter which values the user should enter and these are gradually stored in the given variable. The user is gradually prompted to enter a number. When entering, the name of the variable being filled is displayed. For an array type variable, the user is prompted to enter only "@" (the index is not given). Numbers can only be entered in decimal form.

Examples:
INPUT L,H | the user is prompted to enter values into variables L and then H
INPUT @20, @38 | the user will be asked twice to enter a value in @

Command: LET
Parameters: VAR = EXPR or @VAR = EXPR(,NUM)^
Command function: The assignment statement determines which EXPR value is inserted into the VAR variable.
The statement can also be used to simultaneously fill additional values into multiple array items. After entering a value into a specified array element, it is possible to enter numeric values separated by commas into subsequent elements. The number of values entered is limited only by the length of the line or by reaching the end of the array.

Examples:
LET I=52 | the value 52 is written to I
LET Q= 23*W-L/3 | the expression 23*W-L/3 is first calculated and the result is written to

Q variable
LET @23=4,12,8,63,47 array elements 23 to 27 are filled with the values entered sequentially

Command: GOSUB
Parameters: EXPR
Command function: Calling a subroutine, which can be on reserved program lines. This command is very similar to the GOTO command and does practically the same thing. In addition, however, the return value for the RETURN command is stored. The return value is the line number 1 greater than the line on which the GOSUB command is currently being processed. After executing the subroutine, the RETURN command returns the program to the line given by the return value. Within a subroutine, it is possible to call another subroutine and thus nest subroutines within each other. However, the maximum level is limited to 8 nested subroutines. An attempt to call the ninth subroutine from the eighth nested subroutine will cause an error message and the program to terminate.

Examples:
GOSUB 44 | the subroutine stored on line 44 will be called, after it is terminated
| with the RETURN command, it will continue on the next line

Command: RETURN
Parameters: ---
Command function: Terminate a subroutine. The statement takes the return value stored by the GOSUB command and places it in the pointer to the next line to be executed. Calling the RETURN statement without first calling the GOSUB statement (i.e., missing a return value) will cause an error to be reported and the program to terminate.

Examples:
RETURN | ends the subroutine and returns the program to the line following the
| GOSUB command

Command: CLEAR
Parameters: ---
Command function: Delete the current program. After executing this command, all lines of the program will be empty. If any program was written in the current file (see FILE command), it will be completely deleted.

Examples:
CLEAR | deletes the current program

Command: LIST
Parameters: (NUM)
Command function: Prints the current program in memory. The command can be given without a parameter. In this case, it prints the entire current program stored in the computer's memory. If a number is specified as a parameter, it prints only a specific line. The number can be any, but only the lowest 7 bits are valid (so-called modulo 128 arithmetic).

Examples:
LIST | prints the entire program on the screen
LIST 15 | prints line 15 of the program
LIST 130 | prints line 2 of the program

Command: RUN
Parameters: ---
Command function: Starts program execution. After starting, the program lines are executed sequentially from line 0. If there is no jump command (GOTO or GOSUB) on the given line, the line with a number 1 higher is executed after the current line is executed. Lines on which no command is stored are searched, but no action is performed on them. They represent only a minor delay in the program (the line must be read). For time-critical parts of the program, it is advisable not to leave lines unnecessarily empty. If the line pointer exceeds the value from 127 to 128, the program is automatically terminated.
Line 0 is intended for storing a note in a REM command or for automatic program start. Other functional commands on line 0 will not be executed.
A special case is writing the RUN command in the file FILE 0 (on the disk "h") at the first position of line 0. If the computer finds the RUN command at this position, it automatically starts this program after it is turned on. The computer does not need to have a keyboard connected and can be used, for example, to control a device after debugging the program.

Examples:
RUN | runs the written program

Command: END
Parameters: ---
Command function: Terminates program execution. If the END command is processed during program execution, the program is terminated and the computer returns to the waiting for user command mode. The END command is the only command whose pressing of the appropriate keys (Ctrl + N) is tested during the transition between lines during program execution. When this command is entered on the keyboard, the running program is terminated.

Examples:
END | ends the running program

Command: TIME
Parameters: VAR
Command function: It stores the value from the permanently running internal counter in the variable VAR. The counter is incremented by 1 every time a graphic line is drawn on the VGA monitor since the computer started. To synchronize with the oscillator frequency, the counter runs at a frequency of 31914 Hz. This means that its content is incremented by 31914 every second. Since the counter is 32-bit, it must overflow. After reaching the value 2,147,483,647, which will happen after about 18 hours of operation, the value jumps to the smallest negative number -2,147,483,648 and continues to increase by 1. Further overflows will then always occur after more than 37 hours.
The function can be used not only to monitor the passage of a certain time interval during program execution, but also, for example, as a random number generator. When you press a key and save the current time, you just need to calculate the remainder after dividing the time by the number that determines the generator range.

Examples:
TIME T | stores the time in the variable T
TIME R; LET Q=R/6; LET R=R-Q*6 | in the variable R we get a random number from 0 to 5
| (e.g. for a dice roll)

Command: CURSOR
Parameters: EXPR
Command function: Sets the cursor (the place where writing will be done on the screen) to the specified position. The upper left corner of the screen is position 0 and the lower right corner is position 799. Positions increase on lines from left to right, just as when writing. If the position is outside the allowed range, the command does nothing and the cursor position remains at its original value.
If it is necessary to set the cursor position using a line number, then a calculation can be used where the line number is multiplied by 32 and the character positions within the line are added.

Examples:
CURSOR A | moves the cursor position to the values according to variable A
CURSOR 32*5+15 | moves the cursor to the sixth line from the top and the 16th position
| on that line
CURSOR 1024 | does nothing (value is out of range)

Command: PUTCH
Parameters: EXPR or x EXPR (where x see next) or p EXPR, EXPR
Command function: At the position specified by the cursor (the place where the screen will be written), a character is printed whose value is determined by the parameter expression. The lowest 8 bits are used for the printout. The character is printed in the range 0 to 255 (for higher numbers it will be the remainder after dividing by 256). The drawn character corresponds to the ASCII table. For example, the letter "A" has a value of 65.
Within the ASCII table range, only printable characters from 32 to 127 will be displayed. Above this range, semigraphic characters (mainly lines suitable for various frames) will be displayed in the range 128 to 159. After the semigraphic characters there is an area whose value is expanded as a BASIC keyword. For example, the value 160 will cause the word "PRINT" to be printed.
The remaining characters are non-printable and a dot will appear instead. The only exceptions are 3 values that correspond to the characters "\n", "\t" and "\f", as mentioned for the STRING parameter above:

9 | "\t" - move the cursor on the line to the next higher tab position 0,8,16 or 24
10 | "\n" - newline
12 | "\f" - clears the screen and places the cursor at position 0
The cursor moves in the same way as when printing text using the PRINT command. At the end of a line, a new line is entered and, if necessary, the entire screen is moved.
If one of the following characters is given before EXPR, the cursor moves in a special way:
. | the cursor will remain at the same position
> | the cursor moves one place to the right
< | the cursor moves one place to the left
v | the cursor moves down one place
^ | the cursor moves up one place
In these cases, the line or column is not moved to a new line or column. The cursor moves (and overflows) within the same line or column. In this way, it is possible to print only printable characters in the range 32 to 159.
The last option is to insert a character directly at the specified position on the display without affecting the cursor. After the "p" character, the value of the EXPR character is given, which is inserted at the position specified by the second parameter. The position on the display is in the range 0 to 799, the same as with the CURSOR command. In this way, it is again possible to print only printable characters in the range 32 to 159.

Examples:
PUTCH 49 | prints the number 1 at the cursor position
PUTCH p68, 32*12+10 | prints the letter D on line 12, position 10
PUTCH 12 | clears the screen and sets the cursor to the upper left corner
PUTCH .65 | prints the letter A and leaves the cursor at the same position
PUTCH v67 | prints the letter C and moves the cursor to the lower line with the same
position (in the case of the lowest line, it goes to the highest line)

Command: GETCH
Parameters: VAR or pEXPR, VAR
Command function: It stores the value of the character located at the cursor position on the screen in the variable VAR. Using the CURSOR command, it is possible to set the cursor to any position and using the GETCH command, it is possible to search for what was written at that position. The second option is to specify the position on the display directly after the character "p" in the range 0 to 799, from which the character is taken and stored in the variable VAR.

Examples:
CURSOR 392; GETCH C | the character from position 12,8 on the screen is inserted into
| variable C
GETCH p32*15+4, L | the character from position 4,15 on the screen is inserted into
| the variable L

Command: INKEY
Parameters: VAR
Command function: The command tests whether the user has pressed a key. If no key has been pressed, the value 0 is stored in the variable VAR. If a key has been pressed before the command is called, the corresponding character value according to the ASCII table is stored in the variable. For example, the value 66 means that the user has pressed "B".
Examples:
INKEY C | the character of the key already pressed is inserted into the variable C, or 0 if
| nothing was pressed

Command: FILE
Parameters: (EXPR)
Command function: Depending on the size of the connected memory, the user has at least 1 and at most 16 files available for writing a 128-line program. Switching between these programs is done using the FILE command, where the EXPR expression determines which file (program) will be active. This program is then worked with, written to or read from. EXPR can take on any value, but only the lowest 4 bits are valid (the remainder after dividing by 16). So, for example, the value 17 is equivalent to the value 1.
The size of the memory used determines how many files the user has available. If the smallest memory 24C32 is used, the FILE command has no meaning, because only the file with number 0 is available and it is still active. The larger memory 24LC64 already has two files – 0 and 1. The EXPR expression then allows switching between files, depending on whether the expression is odd or even. With the 24LC128 memory, you can use EXPR to sequentially select files 0,1,2,3,0,1,2,3,0,1... Only the 24LC512 memory uses the full range of this command and selects files numbered 0 to 15.
The FILE command will probably be used most often when changing programs by the user. It can also be used within a running program. This provides a powerful tool that allows you to link different files and jump between them on the fly.
For example, if a program is running in file number 0 and executes the command FILE 3 on line 25, the program continues with line 26 in file 3. This way, the program size limitation of 128 lines can be bypassed. When using the 24LC512 memory and using the option to write up to 3 commands per line, a program of up to 6000 commands can theoretically be placed in memory. In combination with the DISK command (see below), this number increases to 12000.
If the parameter is not specified (or the expression is entered incorrectly), this command prints the current file number on a new line.

Examples:
FILE 10 | switches to file number 10 (for 24LC512 only), to file 0 (for 24C32, 24LC64)
| and to file 2 (for 24LC128 and 24LC256)
FILE | prints the current file number

Command: DISK
Parameters: (h|f)
Command function: The command switches between the memories on the computer board. One of the memories is SMD, firmly soldered to the board and cannot be changed. This memory represents the computer's "hard disk" and is marked “h”. The other memory in DIL can be inserted and removed from the socket and is marked “f”. The integrated circuit can be marked as a "floppy disk"
- a removable medium. After the computer starts, DISK h is active and the file FILE 0 in it.
The parameter determines which disk will be used next – it will be active.
If DISK f is not inserted at startup, the computer will report this in the initial message after switching on. Then, of course, it is not possible to switch to this disk using the DISK f command. The command does nothing and does not report an error. DISK h will remain active.
If the parameter is not specified or is chosen incorrectly, the command will print the active disk designation on a new line.

Examples:
DISK f | switches to DISK f if inserted; otherwise does nothing
DISK | lists active DISK

Command: DELAY
Parameters: EXPR
Command function: Pauses the program for the time specified by the EXPR parameter. The value of the expression specifies the time in milliseconds. Allowed values are 1 to 1,000,000. Outside this range, the command does nothing.

Examples:
DELAY 5*100 the program waits 500 milliseconds and then continues

Command: BEEP
Parameters: EXPR, EXPR
Command function: A small speaker on the board will emit a tone with a frequency specified by the first parameter for a duration specified by the second parameter. The first parameter specifies the frequency in Hz and the allowed values are in the range of 100 to 4000 Hz. Given the parameters of these small sound buzzers, different frequencies will be different loudness and a larger range of values does not make sense.
The second parameter defines the duration for which the tone will sound in milliseconds. Allowed values are between 20 and 100,000 milliseconds. If the parameter range is not respected, the command will not be executed – nothing will be done.

Examples:
BEEP 800, 1500 an 800 Hz tone will sound for 1.5 seconds

Command: REM
Parameters: Any text
Command function: An empty statement that does nothing. It serves only as a comment for the programmer, who can write a short note in the program. The text up to the end of the line is considered a comment.

Examples:
REM Next calculate area of circle | any text can be up to the end of the line.

Command: COPY
Parameters: (h|f)NUM or sNUM,NUM,NUM
Command function: Allows you to copy program source text between files or copy lines within the active file.
The first option causes the contents of the active file will overwrite the file specified in the parameter. The letters h or f specify the disk to which the active file will be written, and the number NUM specifies the target file on that disk. All lines 0 to 127 are copied completely. An exact copy of the file on the given disk is created.
The second parameter specification, indicated by the letter s, copies lines within the active file. The first number (from 0 to 127) specifies the source line where copying will begin. The second parameter (from 0 to 127) selects the location where saving will begin. The third parameter (1 to
127) then specifies how many lines will be copied. If the end of the file is reached during copying, the copying will stop.

Examples:
COPY f6 | copies the active file on disk f to file no. 6
COPY s25,50,20 | copies 20 lines in the active file from line 25 to lines 50 and above

Command: AINP
Parameters: VAR
Command function: The computer has one analog input as standard, allowing you to measure voltage in the range of 0 to 5V. A voltage of 0V is measured as a value of 0, and a maximum voltage of 5V corresponds to a value of 1023. It is important to remember that this is not a precise measuring instrument. The measurement range and accuracy are affected by several factors. However, for ordinary amateur use, this should be sufficient. The value measured by the AINP command is stored in the VAR variable.
Voltages outside the specified range cannot be measured and such voltages can very likely damage the computer!

Examples:
AINP @32 | measure the analog voltage at input A and store it in the array element with
| index 32

Command: DINP
Parameters: VAR, (1|2) - for version with crystal, without crystal: VAR, (1|2|3|4)
Command function: When using a crystal as a source of precise frequency, the computer has 2 digital inputs prepared on the board. If the crystal is not installed and the computer is clocked by an internal oscillator, the number of inputs is expanded to 4. The command reads the state of the input with the specified number into the variable VAR. The value stored in the variable can be either 0 or 1 depending on the logic level at the input. An unconnected input behaves as a logic 1. Using the command switches to the input mode with a weak pull-up to log 1. The pin remains as an input until the DOUT command is used.

Examples:
DINP R,2 | the logical state of digital pin 2 is read into variable R

Command: DOUT
Parameters: EXPR, (1|2) - for version with crystal, without crystal: EXPR, (1|2|3|4)
Command function: The opposite command to the previous DINP command. After its execution, the given digital pin becomes an output with a specified logic level. The command writes the value EXPR to the specified output. If the value is 0, then the output is also logical 0. Any other value then writes a logical 1 to the output. Until the DINP command is used, the pin remains as an output.

Examples:
DOUT 23,2 | the output is set to logical 1 (value is not 0) on digital pin 2

Command: I2CW
Parameters: EXPR
Command function: The computer has relatively few digital inputs and outputs (2 or 4 depending on the board configuration). If this number is not enough for your project, the inputs and outputs can be expanded using a PCF8575 expander board. Then the number is expanded by another 16 digital inputs or outputs. The expander can be connected using a connector with an I2C bus on the board.
Ready-made boards can often be purchased as accessories for Arduino modules, etc. Be careful with the connection of the connectors on the expander board! The PCF8575 board can usually be plugged directly into the connector, but check your expander board!
The command sends the lower 16 bits of the EXPR expression to the expander board. It therefore makes sense to send only a value up to max. 65535.

Examples:
I2CW 61455 | The middle 8 bits in the PCF8575 expander will be 0 padded with 1
| from both the top and bottom.

Command: I2CR
Parameters: VAR
Command function: An additional command to the previous I2CW command – see above. It allows reading the input status from the PCF8575 expander board into the VAR variable.
Again, the standard assumes a 16-bit expander PCF8575. It reads the value up to a maximum of 65535.

Examples:
I2CR H | reads the status from the PCF8575 expander into variable H

### Example program

As an example of a short program, the procedure for displaying all printable characters on the screen was chosen:

0 REM Printable characters
1 PUTCH 12; LET A=32
2 PUTCH A; LET A=A+1
3 IF A<160 THEN GOTO 2

Line 0 is just a comment with the program name and does nothing.
Line 1 first clears the screen by sending the character 12 and then initializes the variable A to 32. Line 2 prints the character from A to the display and increases the value of variable A by one.
Line 3 tests whether the final value has already been reached and if not, then it returns to line 2.

This program allows you to display printable characters on the screen. When you run it, 4 lines of characters appear. The lines start with a character with a value corresponding to 32, 64, 96, and 128.

What to do when...
When using a computer, situations may arise that cause the device to freeze. In these cases, the following procedure may help:
1) If a running program contains an infinite loop, it is possible to interrupt its execution by pressing the RESET button. This performs a so-called cold start on the computer, when all variables are set to zero.
The second option is to enter the END command (Ctlr+N) during program execution. The program interrupted in this way leaves the value of the variables as they were at the moment of interruption. Entering the END command usually leaves this command or only the letter "n" on the command line. It is necessary to additionally delete the rest of the command.
2) If the connected keyboard is manipulated (disconnected and connected) after the computer is turned on, its communication may be disrupted. The keyboard then does not respond or enters incorrect characters. The problem can be solved by pressing the RESET button.
3) The computer has programs stored in a serial EEPROM memory connected to the I2C bus. In case of any interfering signals on the bus, the memory can be blocked and the computer stops responding completely. Often, pressing the RESET button does not help either. In this case, it is necessary to disconnect the computer from the display and turn off the power. After a few seconds in the off state, the computer can be turned on again and connected to the display.
4) Always insert or remove memory from the "DISK f" socket when the computer is turned off (without power)! Hazardous bus conditions when manipulating the memory can damage its contents or the contents of the memory representing the "DISK h". A similar approach is required when connecting or disconnecting an expander with the PCF8575 circuit.

### Commands and parameters:

Command | Ctrl + | Parameters | Note
PRINT | P | (STRING | EXPR) (,(STRING | EXPR))^
IF | U | EXPR RelOp EXPR | RelOp = 7 different operators
THEN | T | STATEMENT
GOTO | G | EXPR | 0 to 127
INPUT | I | VAR (,VAR)^
LET | L | VAR = EXPR or @VAR = EXPR(,NUM)^
GOSUB | H | EXPR | 0 to 126
RETURN | Y
CLEAR | X
LIST | K | (NUM) | Use modulo 128
RUN | R
END | N
TIME | V | VAR | 31914 Hz ticks
CURSOR | W | EXPR | 0 to 799
PUTCH | C | EXPR or x EXPR or p EXPR, EXPR | x choose / p Character, Position
GETCH | , | VAR or p EXPR, VAR | p Position, Variable
INKEY | S | VAR
FILE | F | (EXPR) | Modulo 16
DISK | D | (h|f)
DELAY | M | EXPR | 1 to 1000000
BEEP | Z | EXPR, EXPR | Frequency, Time
REM | E | Any text
COPY | . | (h|f)NUM or sNUM,NUM,NUM | s Source, Destination, Number
AINP | A | VAR
DINP | B | VAR, (1|2) or VAR, (1|2|3|4) | Crystal / without crystal
DOUT | O | EXPR, (1|2) or EXPR, (1|2|3|4) | Crystal / without crystal
I2CW | Q | EXPR | 16 bits
I2CR | J | VAR | 16 bits

^ - repeat option
| - choose from alternative options

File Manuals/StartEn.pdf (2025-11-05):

## How to get started with Tiny BASIC

For complete beginners, the first steps can sometimes be very difficult. To help you get started, here are some examples and tips for getting started with the TinyBasRV microcomputer.

Command or program line

Computers oriented to various versions of the BASIC language usually have a language interpreter running after startup, which simultaneously performs the tasks of an "operating system", a command line and a language translator. It is similar with TinyBasRV. After startup, the computer waits for a command (or several commands) to be executed.
The user can decide whether to directly give the computer the command "to perform a certain action immediately", or to "make a list" of what the computer will do when the user instructs it to start the program.
Both modes (direct command and program writing) work with commands that the computer understands. There are 28 of them in total and you will find them described in detail in the TinyBasLang manual and at the end of it there is a summary table with an overview of the commands.
Tiny BASIC language commands are not entered into the TinyBasRV computer by typing them out one by one using individual characters. The command is passed to the computer by pressing the left Ctrl key and then simultaneously pressing the key according to the table at the end of the TinyBasLang manual.
A typical first example in programming textbooks is a task that forces the computer to say hello. With TinyBasRV, we can achieve this in 2 ways:
1) Enter the command to print the greeting directly
PRINT "Hello"
and then press Enter. The PRINT command is entered as Ctrl+P and then the text is typed between quotes. The computer prints the desired greeting on the next line. The disadvantage is that you have to do this every time you want the computer to say hello.
2) The second option is to write the greeting as a program and then run it. You can imagine that the computer is a servant waiting with a notebook 128 lines long. The computer has lines in the notebook numbered 0 to 127. On each line it can write down the command you enter. After you dictate your commands to it, you can tell it to "now do this according to the list". Some lines may be empty, others may have up to 3 commands per line.
In our case, we can enter into the computer, for example:
1 PRINT "Hello"
After pressing Enter, nothing seems to happen. But the computer has saved our command in its notebook on line 1. And it will wait for more commands. If we now enter the RUN command (Ctrl+R) and press Enter, the computer will start performing tasks in the notebook. On line 1, it will find the command to execute. The result will be the same output as in point 1). The difference is that now we can call up the greeting using the RUN command whenever we want.

More commands per line

Since the microcomputer has a 32-character command line, it would be a shame not to use it. It can write up to 3 commands per line, even with parameters separated by a ; character. You are limited to only 32 characters. You can try writing on one line:
INPUT A,B ; PRINT "Area: " , A*B
And try what it does after you run it with Enter. If you didn't make a mistake in any character while entering the commands, you have a simple tool for calculating the area of a rectangle.
Ver. 2 | 1

You can take advantage of this if you need to write a specific character somewhere on the display screen. You can use a combination of commands
CURSOR 400 ; PUTCH 143
The specified parameter values for commands are printed in a solid square in the middle of the screen.

How a computer processes program lines

If you decide to create a program that the computer will later execute, you can start "dictating" to it on the lines of its notebook what it will do. You can always write on any line from 0 to 127. When you have completed the program, you run it with the RUN command.
The computer will start to go through the individual lines starting from the number 0 and execute the commands it finds on them. It will skip an empty line and move to the next line 1 higher. When it reaches line 127 and should go to the non-existent line 128, it will stop executing the program. Try the following program:
1 INPUT A
5 PRINT "Volume: " , A*A*A
And you have a simple program to calculate the volume of a cube. Try running it.
You can also terminate the program execution at any line using the END command. Add the following line to the program:
3 END
Now, after starting, the computer will prompt you to enter the value A, but it will no longer calculate the volume of the cube. This is because on line 3 it encountered the END command and will not go to line 5.

As a piece of advice, you can take the recommendation for special use of line 0. It is a good idea to learn to write a REM command on line 0 and add a short description of what the program does. After a while, you may not remember what you wanted to create with the program, and a note at the beginning of the program can refresh your memory.

Creating a program - an infinite and counted loop

Computers make their work easier by telling them what to repeat and not having to prescribe each step individually. If we wanted to print out even numbers, we wouldn't prescribe:
1 PRINT 2
2 PRINT 4
3 PRINT 6
…
We will let the computer count by 2 (that's what a computer is for, after all) and we will write the values on lines below each other. For example, like this:
1 LET A=0
2 LET A=A+2 ; PRINT A ; PUTCH 10
3 GOTO 2
The program starts printing even numbers at high speed after it is run. On the first line, we set the value of A to 0. The second line increases the value of A by 2, prints it, and uses the PUTCH command to move the cursor to the next line. Because the GOTO command on line 3 returns the program to line 2 again, an infinite loop has been created that keeps the program running until you turn off or reset the computer. The program can also be interrupted by typing the END command on the keyboard.

If you want to print only a limited number of even numbers (e.g. up to 20), modify line 3 to the new version:
3 IF A<20 THEN GOTO 2
Now when you start the computer, it will print only even numbers up to 20. The conditional IF statement evaluates the condition and returns the program to line 2 only for numbers less than 20. And if you did not delete line 5 from the previous example, it will print as an extra bonus the volume of a cube with sides of 20. You can simply delete line 5 by typing a blank line 5:
5

Statements that are repeated multiple times in a row are usually referred to as a program loop. The IF statement can be entered at the beginning of a loop – for example:
5 IF condition THEN GOTO 21
…
loop statements
…
20 GOTO 5
at the end of the loop, as was shown in the example with the list of even numbers. At first glance, it may seem that it does not matter where the evaluation of the condition is placed. In practice, this often leads to the same program behavior. The main difference, however, is that a loop with an evaluation statement at the end must always be executed at least once. If the test is at the beginning and the condition is met when the loop is first entered, the loop does not have to be executed even once.
Using the IF/THEN and GOTO statements, even in such a simple language, it is possible to create program constructs for which higher-level languages have special statements.

If you need to perform the same operations repeatedly with different parameters during a program, you can use a so-called subroutine. As an example of a subroutine, we can demonstrate something that, when called, will cause the speaker to beep several times according to the value in variable A. 40 BEEP 1000,200 ; DELAY 200
41 LET A=A-1; IF A>0 THEN GOTO 40
42 RETURN
In the program, I can now insert the line: whenever I need to signal several beeps with sound:
23 LET A=5 ; GOSUB 40
On the given line, I set the number of times to beep in variable A and then call the subroutine on line 40. It will make the appropriate number of beeps and using the RETURN command on line 42, the program will return to the line 1 number higher than where it was called from. In our case, the program would continue on line 24.

Where the program is stored (FILE and DISK commands)

The microcomputer stores the entered program in its serial EEPROM memory. Since one notebook is not enough for a good servant, our computer also has the possibility of equipping itself with multiple notebooks. It is clear that a program for taking care of the garden is different from a program for cleaning the house or maintaining a car.
Depending on the type of installed memory, 1 to 16 programs can be stored in it. The types of memories and the number of programs are summarized in the table in the TinBasHW manual. You can switch between programs using the FILE command. For example:
FILE 3
switches to the file with program 3 (gives our servant notebook number 3 in his hand). This program (notebook in his hand) will remain current until a new FILE command. After the computer starts, program 0 is default. If you are not sure which program is currently switched, enter the FILE command without a parameter and the computer will answer you with its number.
To make it not so simple, our servant can have 2 bookcases and each of them has more notebooks. It is possible to mount 2 serial EEPROM memories on the computer board. In order to distinguish between them, one is marked "h" (like a hard disk) and is firmly soldered to the board. The other is marked "f" (like a flash or floppy disk). If a socket is used, it can be removed when turned off and a new one inserted in its place.
Switching between EEPROM memories is done with the DISK command – for example:
DISK f
Again, if you are unsure, you can enter the command without any parameters and the computer will tell you which disk is active. After booting, it is always disk h.

Interface with the outside world – warning light

To try working with outputs and simple control of external peripherals, you can try connecting two red LEDs to digital outputs D1 and D2 via resistors according to the following diagram:


Let's load a simple program into memory:
1 DOUT 1,1; DOUT 0,2
2 BEEP 2000,100; BEEP 800,200; DELAY 200 3 DOUT 0,1; DOUT 1,2
4 BEEP 2000,100; BEEP 800,200; DELAY 200
5 GOTO 1
This will give us a simple warning device for a railway crossing with an audible signal. On lines 1 and 3 we always turn on one LED (and turn off the other). Lines 2 and 4 are the same and make an audible signal and a short delay. Line 5 then loops the program.

Expander

If you have an expansion board with a PCF8575 expander available, you can control a larger number of LEDs. This allows you to create, for example, a "running arrow" or other lighting effect. Connect the required number of LEDs (max. 16 pcs) to the expander outputs, always according to the picture:

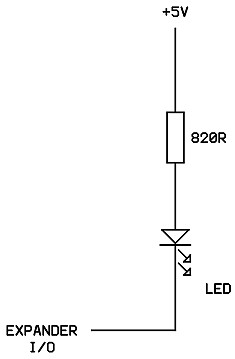
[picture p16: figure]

You can turn on the LEDs you want to light up with the command (for 8 LEDs):
I2CW b11110100
The binary digits in the parameter determine what will be lit – position 0, and what will be off – 1. If you want a running light, you can create it for 8 LEDs like this:
1 LET A=-2
2 I2CW A ; DELAY 200
3 LET A=A*2+1
4 IF A < -300 THEN LET A=-2
5 GOTO 2
This is where the magic of computer mathematics comes into play. The number -2 is made up of all 1s and one 0. The operation A*2+1 then moves this 0 up 1 position.

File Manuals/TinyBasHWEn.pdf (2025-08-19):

## Hardware TinyBasRV ver. 1.0

Parameters:
Supply voltage: | 5 V
Current consumption: | 100 mA max
Inputs and outputs: | 2 (or 4) digital + 1 analog input
Expansion modules: | expander with PCF8575

The TinyBasRV microcomputer is a simple circuit that allows a beginner hobby electrician to build his own easy-to-use and programmable computer. To use it, you just need to connect a +5V power supply, a computer keyboard with a PS2 connector and a monitor with input from a VGA card. All computer components are located on one side of a two-layer printed circuit board measuring 65 x 70 mm. The circuit can be divided into several parts and further modified by the user according to the needs and availability of components. The complete circuit diagram is shown in the following figure.

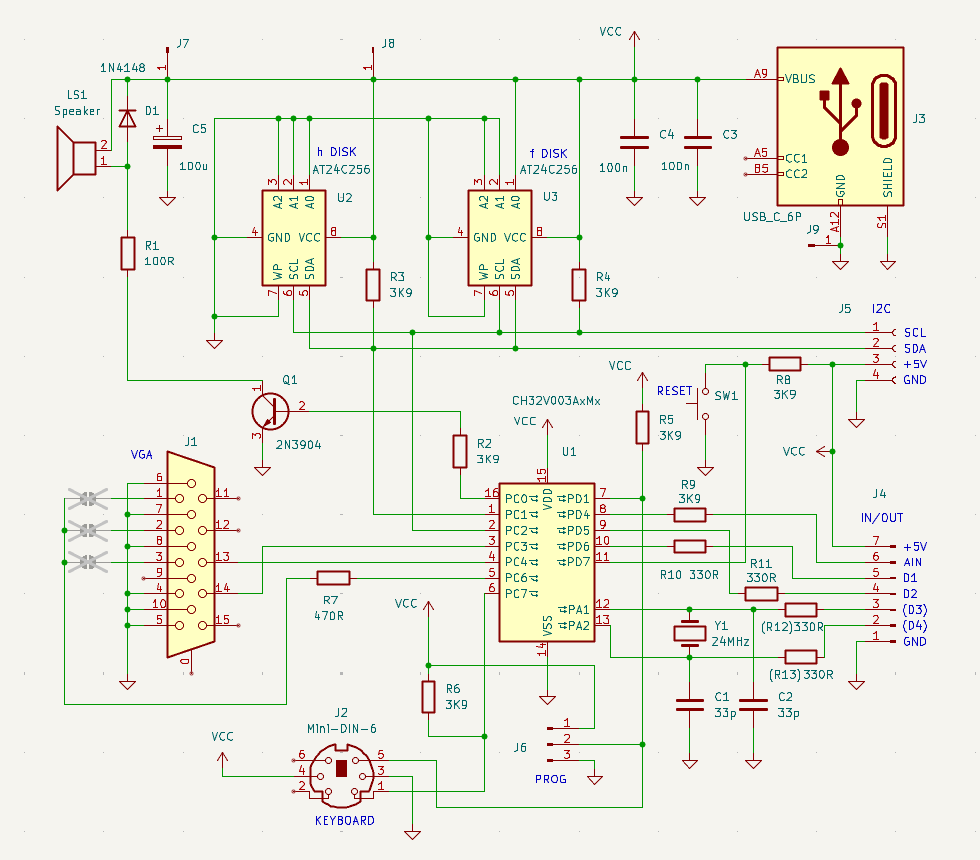
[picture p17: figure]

Rev B | 1

### Computer core

The components necessary for the computer to function are integrated circuits U1 and U2 (respectively U3), resistors R3 to R7, capacitors C3 to C5, and connectors J1 and J2. This represents the minimum number of components that must be mounted on the printed circuit board.
The 32-bit RISC-V processor U1 receives commands from the keyboard connected to connector J2. Resistors R5 and R6 maintain a quiescent level of log. 1 on the keyboard bus. The output for the user is the information displayed on the VGA display. The actual video signal is generated on pin PC6. Its level is adjusted to the required level via a divider consisting of resistor R7 and the monitor input resistor. Vertical and horizontal image synchronization is generated on pins PC3 and PC4. The monitor connection is provided by a three-row D-SUB connector J1.
The processor has the program data stored in the serial EEPROM memory U2 (or U3). Communication with it takes place over the I2C bus, which again needs resistors R3 and R4 to maintain the quiescent level at log. 1. The memory U2, referred as "DISK h", has all address inputs A0 to A2 connected to log. 0 and thus has the address set to 0. The memory, like the processor, is SMD and is permanently soldered to the board.
The remaining components, i.e. capacitors C3 to C5, are for blocking the supply voltage.

Computer power supply
The computer requires a stabilized +5V supply voltage. This can be connected directly to the printed circuit board using wires in the holes next to the capacitor C5 (J8 is +, J9 is GND). It is also possible to power the computer from a power adapter with a USB type C connector. The board has contact areas for soldering a 6-pin type C power connector.

### Optional parts:

Accurate time base
The U1 processor can be clocked from the internal RC oscillator. However, due to the accuracy and stability of this oscillator, the computer timing will not be accurate and this will also affect the stability of the VGA monitor image. The individual displayed lines will be visibly jittery in the horizontal direction.
For a stable image, it is better to use timing using an external 24 MHz crystal at position Y1 with capacitors C1 and C2. If a crystal is used, it is not possible to use the digital inputs/outputs D3 and D4. The processor pins will be blocked by the time base. Capacitors C1 and C2 are placed in the position on the board prepared for R12 and R13. The second pin is soldered to the closer hole connected to GND. R12 and R13 are not installed.

Audio output
In order for the computer to emit various tones, it has a sound section. The basis is a miniature speaker LS1 driven by a transistor Q1. Resistor R1 limits the current flowing through the speaker and R2 determines the current to the base of the transistor. Diode D1 is protective and serves to suppress voltage peaks that would arise when the current through the speaker is turned off.

RESET circuit
If the computer stops responding to user commands, it can be reset to its initial state using the RESET button. Resistor R8 maintains a quiescent level of log. 1 on the processor reset input. After pressing the SW1 button, the level is changed to log. 0 and the computer is RESET.

Expandable memory
In addition to the U2 memory, there is also a slot on the board for another serial EEPROM memory

U3. This time, the type in the classic DIL8 pinout design is chosen so that it can be inserted and removed from the socket. The memory has a preset address of 1 (address input A0 is at logic 1) and represents a "floppy" DISK f. The memory can be used in the same way as DISK h. It is therefore possible to install a socket on the board for future use of a second memory. This is suitable if you want to expand the size of the computer's program memory or for the possibility of transferring programs between different TinyBasRV computers.

I2C bus expansion
The computer has relatively few inputs and outputs in case the user wants to control larger peripherals. In this case, the I2C bus can be used, through which the memories communicate. If you install a 4-pin connector in position J5, you can connect a PCF8575 expander board to it. This will increase the number of digital inputs/outputs by 16. Be careful when connecting external circuits to the I2C bus and always do it in the off state. The bus transfers data between the processor and memories and a disturbing signal can damage the written program.

Inputs and outputs
The user can have several inputs and outputs on the J4 connector to control various devices. One input AIN is analog and allows measuring voltages from 0 to 5V. Other inputs/outputs are digital and can be 2 if a crystal is used, or 4 without a crystal. If a specific pin is input or output, it is determined by the program. All inputs/outputs are ready for mounting protective resistors R9 to R11 (or R13). When choosing a crystal time base, inputs/outputs D3 and D4 cannot be used. Resistors R12 and R13 must not be mounted, because capacitors C1 and C2 are expected to be placed in one of their holes.

### Building a computer

All computer components are mounted on one side of a double-sided printed circuit board. It is only necessary to place the components marked above as the core of the computer on the board and ensure its power supply.

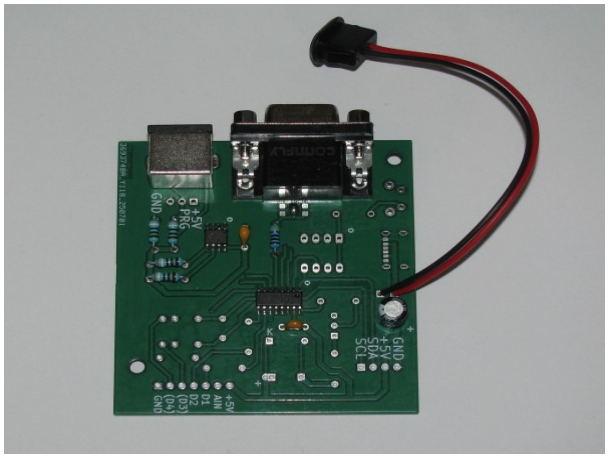
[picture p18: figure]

The picture shows a minimal version of a microcomputer. The remaining elements are optional.

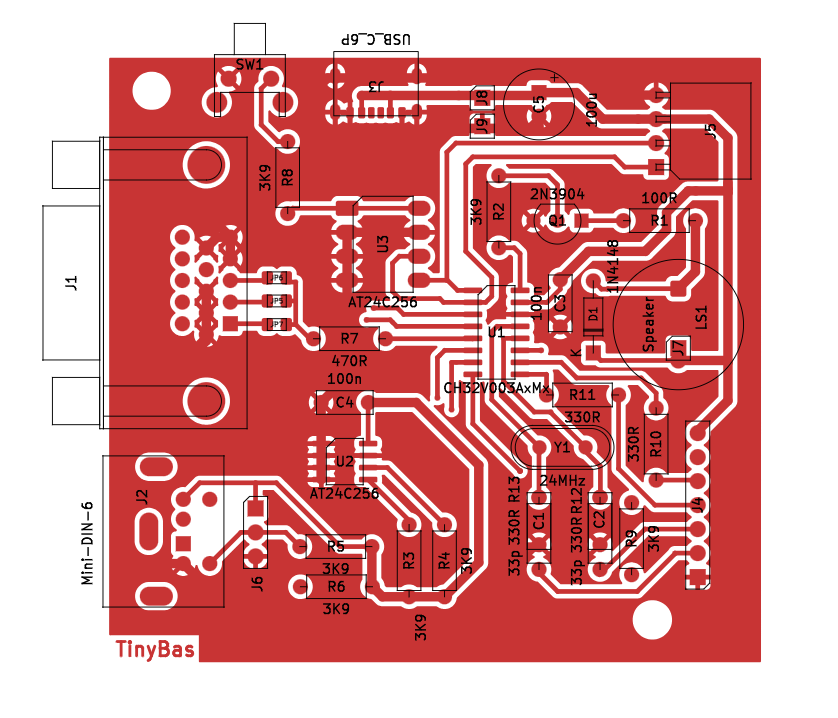
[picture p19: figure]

### Recommended assembly procedure

When building a microcomputer, it is advisable to start by soldering the U1 processor and the C3 capacitor to the board. Then, you can use the WCH-LinkUtility program to program Tiny BASIC into the computer's memory. To write the program into the memory, you need the WCHLinkE programmer (Caution! A programmer without an "E" will not work!). The WCH-LinkUtility program can be found on the website of the CH32V003 processor manufacturer and is freely downloadable. In the program window, you usually just need to select the correct processor type and enter the HEX file with the programming data.

The WCH-LinkUtility program is also part of the MounRiver Studio programming environment. However, it is well hidden. In version 2.10, you can find it in the folder:

c:\MounRiver\MounRiver_Studio2\resources\app\resources\win32\components\WCH\Others\ SWDTool\default\WCH-LinkUtility.exe

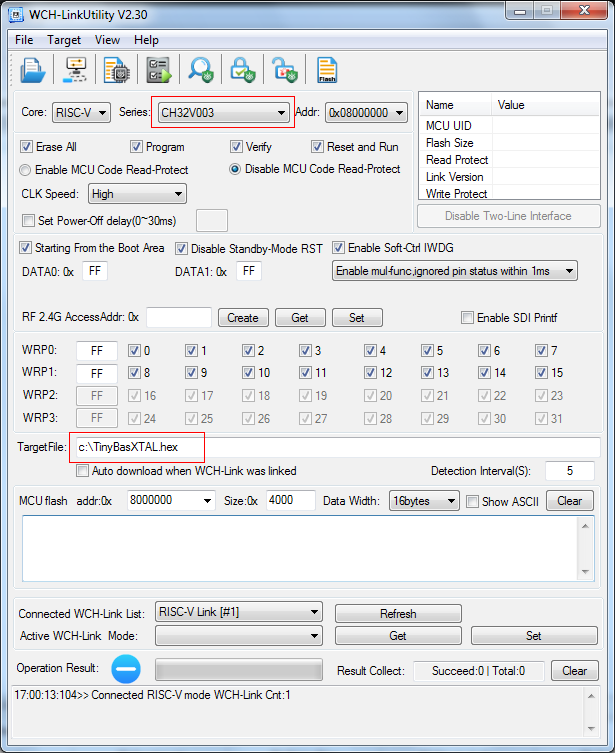
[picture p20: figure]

There are 2 versions of HEX files in the Bin directory. The user must decide which version to use. If the crystal is planned to be mounted on the board, select the program "...XTAL...". If the crystal will not be used, download and load the version "...RC..." into memory of CH32V003.
For programming purposes, the J6 connector is prepared on the board. If you do not plan to rewrite new versions of Tiny BASIC frequently, there is no need to install the connector. The WCHLinkE programmer can be connected with 3 wires directly to the holes for J6 on the board. The GND, SDIO and +5V signals on the programmer are connected to the board. Then just enter Target – Program.

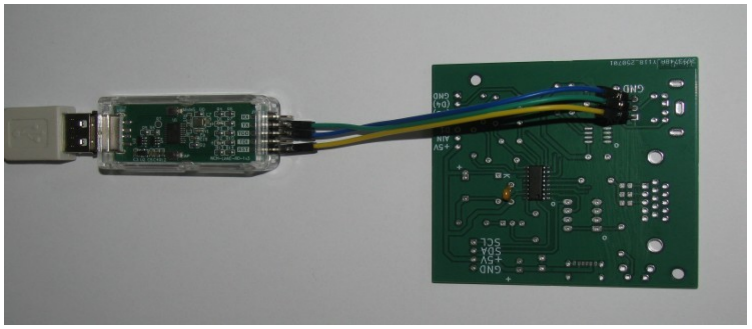
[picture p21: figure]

If necessary, the processor content can be overwritten with a new version in the future. The keyboard must not be connected to connector J2 during programming!

After successfully programming the processor, we can proceed to installing other components. As mentioned above, it is necessary to install the computer core (U1, C3 to C5, R3 to R7, J1, J2 and at least one of the EEPROM memories). The remaining parts of the computer and their components are optional, they are not necessary for the basic functioning of the device.
For a complete computer, you still need to choose the color of the display on the monitor. There are 3 jumpers prepared for shorting with a drop of tin near the J1 connector. You can choose the color red, green, or blue. If you have a monochrome monitor, you need to connect the middle (green) jumper.

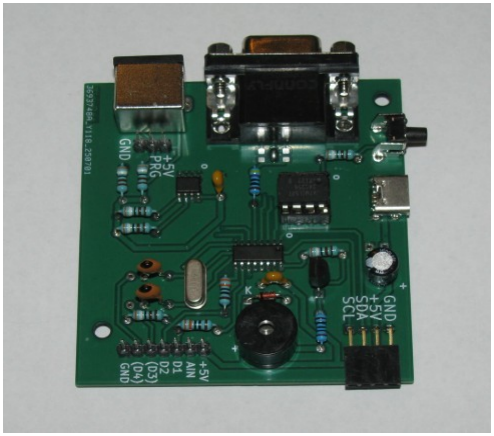
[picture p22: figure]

### Parts list

Position | Type | Note
U1 | CH32V003A4M6 | 32bit RISC-V
U2 | EEPROM I2C – see below | SOIC8
U3 | EEPROM I2C - see below | DIL8 + socket!
Q1 | 2N3904 | TO92 or a similar NPN type
D1 | 1N4148 | Or a similar type
R1 | 100R | 0207
R2 to R6, R8, R9 | 3K9 | 0207
R7 | 470R | 0207
R10 to R13 | 330R | 0207
C1,C2 | 33p | ceramic
C4,C4 | 100n | ceramic
C5 | 100u/16 | electrolytic
Y1 | 24 MHz | THT crystal low
LS1 | Miniature speaker 16Ω | Diameter 12 mm
SW1 | Side microswitch | E.g. TS6606-8.0-180
J1 | D-SUB 15 pin (5x3) | Female to PCB
J2 | Mini DIN 6 pin | Female to PCB
J3 | USB C 6 pin | E.g. USB4125
J4, J6 | 7 + 3 Male Header | 2.54 mm straight pin header
J5 | Female header 4 pins | 2.54 mm for PCB 90°

### Memory types and number of programs

It is possible to connect various serial I2C EEPROM memories to the computer board according to current availability and user requirements. When choosing a memory, check whether the memory manufacturer allows a supply voltage of 5V and a bus speed of 400 kHz. Different manufacturers mark their type series differently, e.g. 24LC256, 24AA256, M24512, etc. The table therefore shows the basic numerical marking, which is usually supplemented by other letter combinations.

Type | Size | Number of programs | Program designations
2432 | 32 Kbit / 4 KByte | 1 | 0
2464 | 64 Kbit / 8 KByte | 2 | 0,1
24128 | 128 Kbit / 16 KByte | 4 | 0,1,2,3
24256 | 256 Kbit / 32 KByte | 8 | 0,1,2,3,4,5,6,7
24512 | 512 Kbit / 64 KByte | 16 | 0,1,2,3,4,5,6,7,8,9,10,11,12,13,14,15

The "Number of Programs" column indicates how many individual Tiny BASIC programs can be stored in memory. The last column then refers to the numerical designation of the individual programs written in memory.

If you have a serial I2C EEPROM programmer, you can use the I2C bus on connector J5. When you correctly connect the 4 wires from the connector to the socket of the EEPROM programmer, you can load the contents of the file ExampleBas.hex, which is in the EEPROM_examples folder, into the EEPROM. The file is 32 Kbytes in size, so it is suitable for 24256 and 24512 memories. If you succeed, you will get 8 sample programs in the Tiny BASIC language. For more information about the programs, see the TinyBasExamples manual.

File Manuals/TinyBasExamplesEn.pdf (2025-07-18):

## Tiny BASIC program examples

The file ExampleBas.hex contains 8 Tiny BASIC files for the TinyBasRV microcomputer. If we load them into the serial EEPROM memory 24256 or 24512, we get simple sample programs for an overview of what can be easily created with the microcomputer. The programs can also be used for testing functions and modifying the attached samples.
After writing the ExampleBas.hex file to memory, you can run these programs:

Program: FILE 0

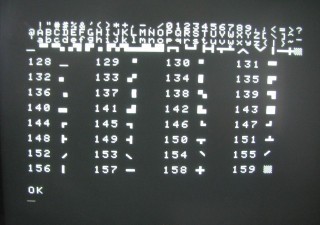
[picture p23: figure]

Purpose of the program: Example of character on the display
Program description: The top 4 lines list all printable characters. The first 3 lines are characters corresponding to the ASCII table from value 32 to value 127. The fourth line shows semigraphic characters from value 128 to 159. The semigraphic characters are then repeated in a table where each character is assigned its value.

Program: FILE 1

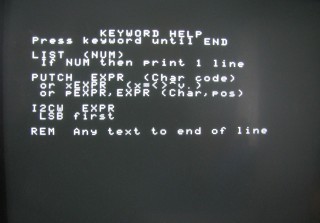
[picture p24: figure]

Purpose of the program: Tiny BASIC command parameter help
Program description: After entering the command, its parameters appear, possibly with a short comment. The program demonstrates the use of calling the GOSUB subroutine based on the calculated line number.

Program: FILE 2

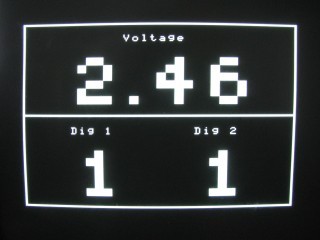
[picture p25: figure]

Purpose of the program: Analog input, digital inputs and graphics test

Program description: Example of how to store fonts for digits in a 4x6 dot grid in variables in the @ field. A frame is then created on the screen, into which the analog value from the AIN input converted to voltage is written in the upper part. The status of the digital inputs D1 and D2 is displayed in the lower part. The AIN input can be used, for example, to measure the voltage on alkaline or lithium cells (AIN must always be at +).

Program: FILE 3

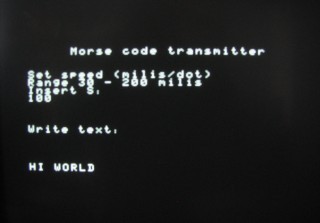
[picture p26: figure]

Purpose of the program: Acoustic and optical Morse code transmitter
Program description: The @ field first stores the Morse codes of the symbols in the form 1113, where 3 represents a comma and 1 represents a dot. According to the standard, a comma should be 3 times longer than a dot. The characters are encoded in the opposite way. The right digit is transmitted first and then the sequence continues to the left as long as there are digits in the code. The user can enter text up to 64 characters long and after pressing Enter the text is transmitted audibly. At the same time, the code is also signaled optically when an LED is connected to output D1. Initially, it is possible to enter the duration of the dot in milliseconds as a parameter.

Program: FILE 4

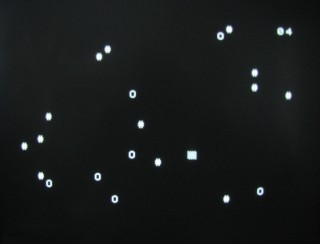
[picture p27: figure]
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

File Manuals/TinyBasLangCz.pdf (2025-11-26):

# Tiny BASIC

# pro

# TinyBasRV

Rev C | 1

## Programové vybavení ver. 1.0

Mikropočítač TinyBasRV obsahuje interpreter jazyka Tiny BASIC s některými omezeními a naopak s řadou vylepšení. Interpreter zajišťuje uživatelské rozhraní (komunikaci s obsluhou) a také vykonávání uloženého programu.
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

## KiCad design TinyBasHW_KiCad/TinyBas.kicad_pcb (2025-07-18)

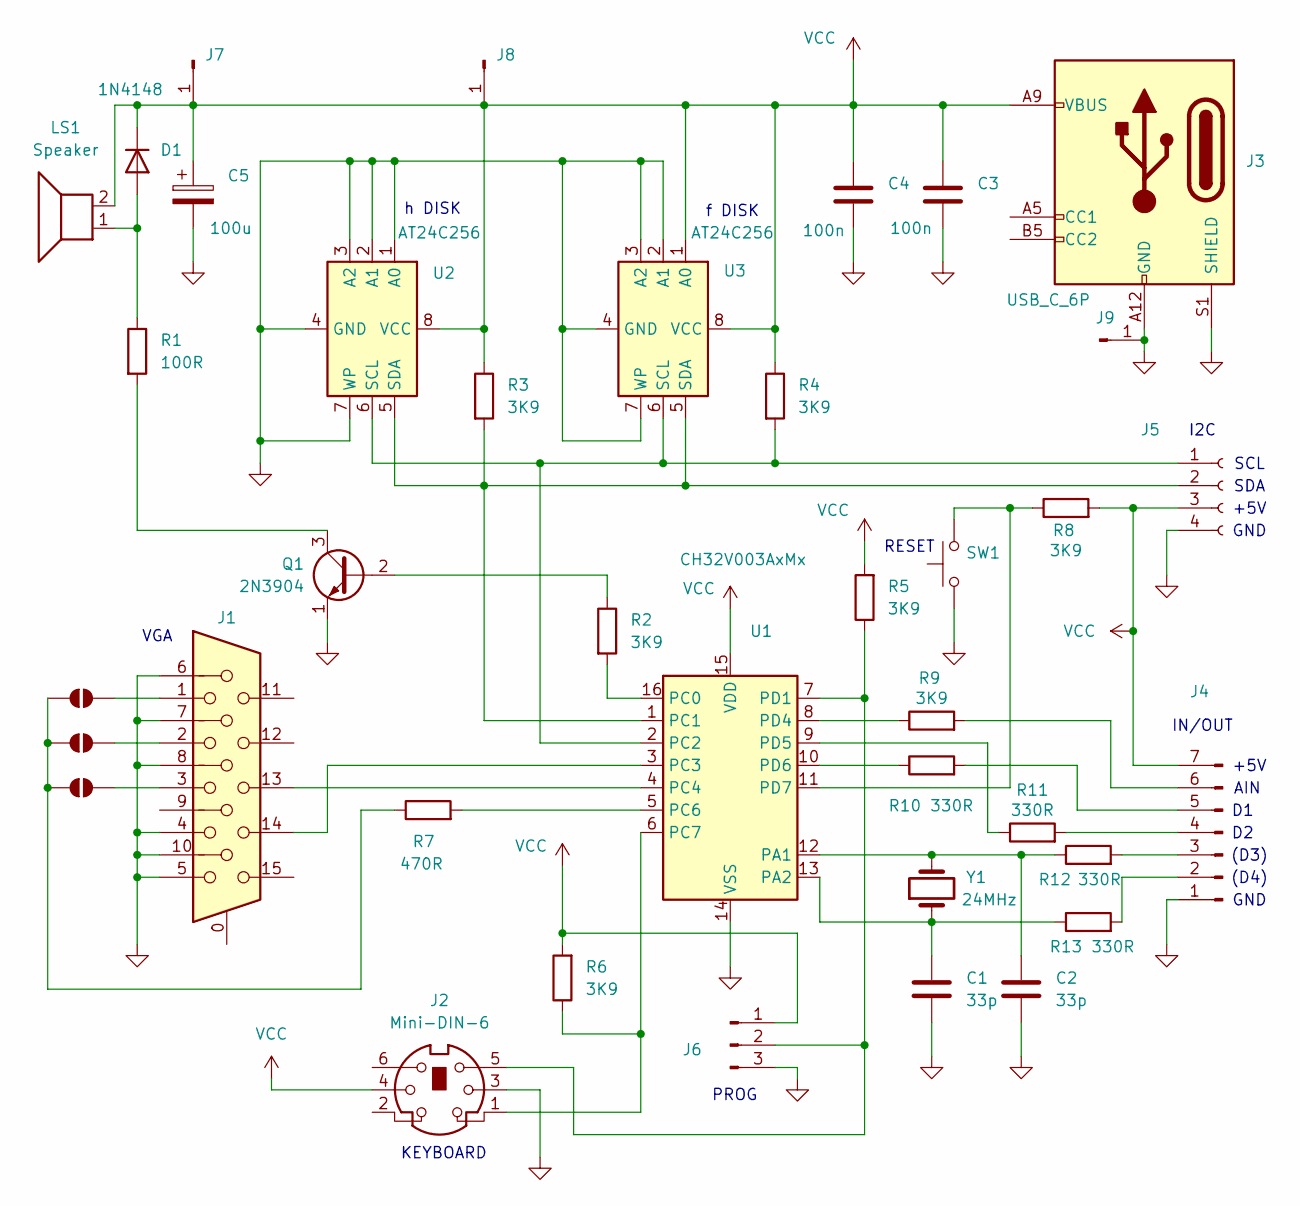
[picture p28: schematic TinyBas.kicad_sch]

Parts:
C1, C2: 33p; C_Disc_D6.0mm_W2.5mm_P5.00mm
C3, C4: 100n; C_Disc_D6.0mm_W2.5mm_P5.00mm
C5: 100u; CP_Radial_D7.5mm_P2.50mm
D1: 1N4148; D_DO-35_SOD27_P7.62mm_Horizontal
J1: DE15_Socket_HighDensity_MountingHoles; DSUB-15-HD_Socket_Horizontal_P2.29x2.54mm_EdgePinOffset8.35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
J2: Mini-DIN-6; Connector_Mini-DIN_Female_6Pin_2rows
J3: USB_C_6P; USB_C_Receptacle_GCT_USB4125-xx-x_6P_TopMnt_Horizontal
J4: Conn_01x07_Pin; PinHeader_1x07_P2.54mm_Vertical
J5: Conn_01x04_Socket; PinSocket_1x04_P2.54mm_Horizontal
J6: Conn_01x03_Pin; PinHeader_1x03_P2.54mm_Vertical
J7, J8, J9: Conn_01x01_Pin; PinHeader_1x01_P2.54mm_Vertical
JP5, JP6, JP7: SolderJumper_2_Open; R_0805_2012Metric_Pad1.20x1.40mm_HandSolder
LS1: Speaker; Indicator_PUI_AI-1440-TWT-24V-2-R
Q1: 2N3904; TO-92_Inline_Wide
R1: 100R; R_Axial_DIN0207_L6.3mm_D2.5mm_P7.62mm_Horizontal
R2, R3, R4, R5, R6, R8, R9: 3K9; R_Axial_DIN0207_L6.3mm_D2.5mm_P7.62mm_Horizontal
R7: 470R; R_Axial_DIN0207_L6.3mm_D2.5mm_P7.62mm_Horizontal
R10, R11, R12, R13: 330R; R_Axial_DIN0207_L6.3mm_D2.5mm_P7.62mm_Horizontal
SW1: SW_Push; SW_Tactile_SKHH_Angled
U1: CH32V003AxMx; SOP-16_3.9x9.9mm_P1.27mm
U2: AT24C256; SOIC-8_3.9x4.9mm_P1.27mm
U3: AT24C256; DIP-8_W7.62mm_LongPads
Y1: 24MHz; Crystal_HC49-U_Vertical

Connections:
GND: C1.2, C2.2, C3.2, C4.2, C5.2, J1.4, J1.5, J1.6, J1.7, J1.8, J1.10, J2.3, J3.A12 (GND), J3.B12 (GND), J3.S1 (SHIELD), J4.1, J5.4, J6.3, J9.1, Q1.1 (E), SW1.1, U1.14 (VSS), U2.1 (A0), U2.2 (A1), U2.3 (A2), U2.4 (GND), U2.7 (WP), U3.2 (A1), U3.3 (A2), U3.4 (GND), U3.7 (WP)
unnamed: D1.2 (A), LS1.1, R1.1
unnamed: J4.2, R13.2
unnamed: J4.3, R12.2
unnamed: J4.4, R11.2
unnamed: J4.5, R10.2
unnamed: J4.6, R9.2
unnamed: J5.1, R4.2, U1.2 (PC2), U2.6 (SCL), U3.6 (SCL)
unnamed: J5.2, R3.2, U1.1 (PC1), U2.5 (SDA), U3.5 (SDA)
unnamed: J2.5, J6.2, R5.1, U1.7 (PD1)
unnamed: JP5.1 (A), JP6.1 (A), JP7.1 (A), R7.1
unnamed: J1.2, JP5.2 (B)
unnamed: J1.3, JP6.2 (B)
unnamed: J1.1, JP7.2 (B)
unnamed: Q1.2 (B), R2.1
unnamed: Q1.3 (C), R1.2
unnamed: C2.1, R12.1, U1.12 (PA1), Y1.2
unnamed: C1.1, R13.1, U1.13 (PA2), Y1.1
unnamed: R2.2, U1.16 (PC0)
unnamed: J1.14, U1.3 (PC3)
unnamed: J1.13, U1.4 (PC4)
unnamed: R7.2, U1.5 (PC6)
unnamed: J2.1, R6.1, U1.6 (PC7)
unnamed: R9.1, U1.8 (PD4)
unnamed: R11.1, U1.9 (PD5)
unnamed: R10.1, U1.10 (PD6)
unnamed: R8.1, SW1.2, U1.11 (PD7)
VCC: C3.1, C4.1, C5.1, D1.1 (K), J2.4, J3.A9 (VBUS), J3.B9 (VBUS), J4.7, J5.3, J6.1, J7.1, J8.1, LS1.2, R3.1, R4.1, R5.2, R6.2, R8.2, U1.15 (VDD), U2.8 (VCC), U3.1 (A0), U3.8 (VCC)

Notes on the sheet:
f DISK
KEYBOARD
h DISK
PROG
RESET
SCL
+5V
(D4)
GND
(D3)
AIN
VGA
IN/OUT
SDA
I2C

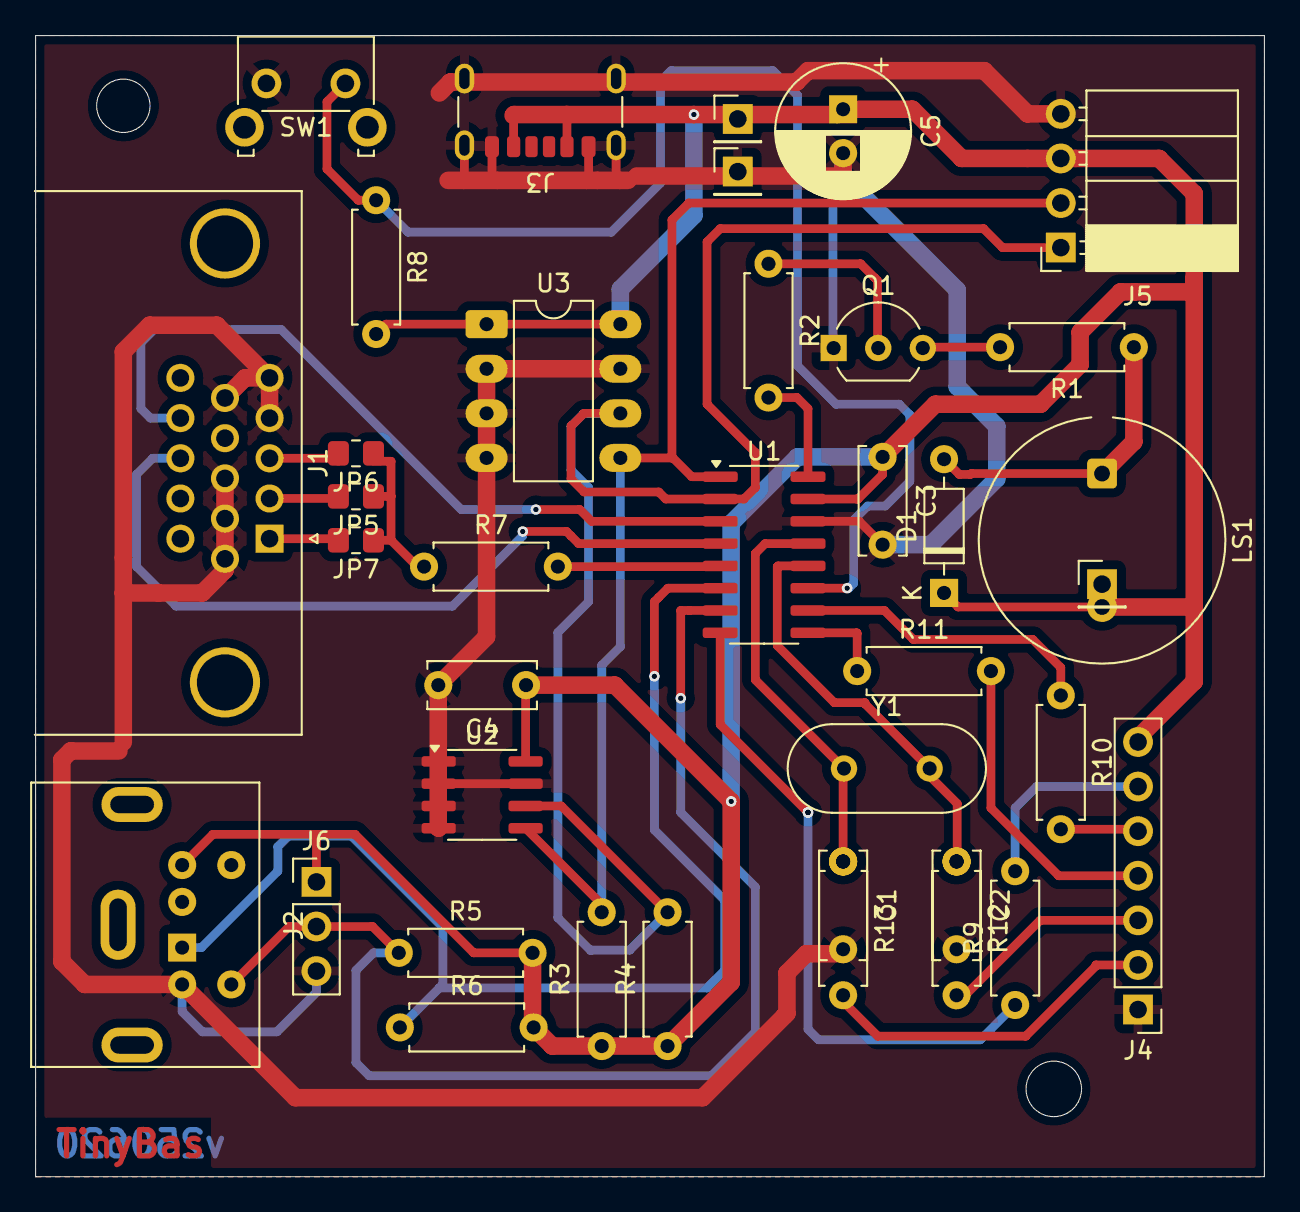
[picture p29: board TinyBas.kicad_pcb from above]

Board: 2 copper layers, 70.0 x 65.0 mm, 38 parts (0 on the bottom side), 28 nets.

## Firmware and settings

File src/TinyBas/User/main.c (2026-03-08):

/********************************** (C) COPYRIGHT *******************************
 * File Name          : main.c
 * Author             : Stan6314
 * Version            : V1.0a (speed up TIM1_UP_IRQHandler)
 * Date               : 2026/03/08
 * Description        : TinyBasic for CH32V003
 *      + character constants are in charstable.h
 *      + oscillator settings mus be written to systemv00x.c
 * The program contains 3 parts:
 *      -> initialization, interrupt and auxiliary functions
 *      -> Tiny BASIC commands
 *      -> main loop
*********************************************************************************
*******************************************************************************/
// When using an external 24MHz crystal, uncomment the following #define line and
// change the settings #define SYSCLK_FREQ_48MHZ_HSI 48000000 to #define SYSCLK_FREQ_48MHz_HSE 48000000
// in the file system_ch32v00x.c
// For RC oscillator line must be commented and #define SYSCLK_FREQ_48MHZ_HSI 48000000 in the file system_ch32v00x.c
//#define SYSCLK_EXT_CRYSTAL

#include "debug.h"
#include "ch32v00x_dma.h"
#include "charstable.h"

// Global variables for VGA display
u_int16_t nVGAline;                // VGA displayed line counter (0 - 525)
volatile u_int8_t DMABuff[47];      // Buffer for DMA to SPI transfer
volatile u_int8_t VideoRAM[800];    // VideoRAM for 25 * 32 chars
volatile u_int16_t nDispChar=0;    // Which character (line) will be displayed
volatile u_int32_t basTimer;      // Internal timer for Tiny BASIC TIME command incremented with vertical sync

// Global variables for Tiny BASIC
static uint16_t dispPointer = 0;      // Pointer to current display position
volatile uint8_t RunMode = 0;     // If it is 1, then basic program is in run
uint8_t currentLine=0;    // Actual line to proccess
uint8_t noOfMemory = 0;  // Number of section in program memory or "file" (4 KB sections)
uint8_t compFlags = 0;  // Bit7 = Is DISK1, Bit6 = Is PCF857x, Bits3-0 = Low Addres of EEPROM (Disk adr)
uint8_t linePointer=0;    // Pointer to line memory buffer
uint8_t line_buffer[33];  // buffer for data read/write
uint8_t stack_buffer[8];  // buffer for GOSUB stack
uint8_t stackPointer=0;    // Pointer to GOSUB buffer
int charVariable[26]; // Variables A..Z
int arrayVariable[100]; // Variables in array @0..99
int evalNumber;     // Value of number for evaluation in BASIC line

/*********************************************************************
    Functions for keyboard
 *********************************************************************/
// Assignment input pins (DATA and CLOCK) for keyboard
#define KBD_CLOCK_PORT    GPIOD
#define KBD_CLOCK_PIN     GPIO_Pin_1
#define KBD_DATA_PORT     GPIOC
#define KBD_DATA_PIN      GPIO_Pin_7
#define KBD_INT_PORT_SRC  GPIO_PortSourceGPIOD
#define KBD_INT_PIN_SRC   GPIO_PinSource1
#define KBD_INT_LINE      EXTI_Line1

// HW keyboard initialization - pins and interrupt
void kbd_init() {
  // Pins of Port configuration 
	GPIO_InitTypeDef Config = {0};
	Config.GPIO_Pin = KBD_CLOCK_PIN;
	Config.GPIO_Mode = GPIO_Mode_IN_FLOATING;
	Config.GPIO_Speed = GPIO_Speed_50MHz;
	GPIO_Init(KBD_CLOCK_PORT, &Config);
	Config.GPIO_Pin = KBD_DATA_PIN;
	GPIO_Init(KBD_DATA_PORT, &Config);
  // Keyboard interrupt configuration
	EXTI_InitTypeDef kbd_exti = {0};
  RCC_APB2PeriphClockCmd(RCC_APB2Periph_AFIO, ENABLE);
	GPIO_EXTILineConfig(KBD_INT_PORT_SRC, KBD_INT_PIN_SRC);
  kbd_exti.EXTI_Line = KBD_INT_LINE;
  kbd_exti.EXTI_Mode = EXTI_Mode_Interrupt;
  kbd_exti.EXTI_Trigger = EXTI_Trigger_Falling;
  kbd_exti.EXTI_LineCmd = ENABLE;
  EXTI_Init(&kbd_exti);

	NVIC_InitTypeDef kbd_nvic = {0};
	kbd_nvic.NVIC_IRQChannel = EXTI7_0_IRQn;
  kbd_nvic.NVIC_IRQChannelPreemptionPriority = 0;
  kbd_nvic.NVIC_IRQChannelSubPriority = 1;
  kbd_nvic.NVIC_IRQChannelCmd = ENABLE;
  NVIC_Init(&kbd_nvic);
}

// Keyboard variables
static uint16_t KbdBuffer = 0;      // Buffer for received data
static uint8_t KbdReady = 0;        // Flag full buffer (11 bits received)
static uint8_t KbdBitCnt = 0;       // Counter received bits from keyboard
volatile uint8_t KbdData = 0;       // Keyboard code output (bits in reverse order)
volatile uint8_t KbdStatus = 0;     // Status flags for keyboard
// Bit 3 = Key released UP, Bit 2 = RShift, Bit 1 = LShift, Bit 0 = Ctrl

// Function translate keyboard code from KbdData to ASCII or statement character
uint8_t kbdRead() {
  uint8_t RetKey = 0;
  uint8_t KeyCode = KbdData; // Strobe volatile data to auxiliary variable
	if(KeyCode) {   // Is key code in reverse order, so translate it
        KbdData = 0;
        // Test letter codes and and adjust capital letters
        switch (KeyCode) {
            case 0x38: RetKey = 'a'; break;
            case 0x4C: RetKey = 'b'; break;
            case 0x84: RetKey = 'c'; break;
            case 0xC4: RetKey = 'd'; break;
            case 0x24: RetKey = 'e'; break;
            case 0xD4: RetKey = 'f'; break;
            case 0x2C: RetKey = 'g'; break;
            case 0xCC: RetKey = 'h'; break;
            case 0xC2: RetKey = 'i'; break;
            case 0xDC: RetKey = 'j'; break;
            case 0x42: RetKey = 'k'; break;
            case 0xD2: RetKey = 'l'; break;
            case 0x5C: RetKey = 'm'; break;
            case 0x8C: RetKey = 'n'; break;
            case 0x22: RetKey = 'o'; break;
            case 0xB2: RetKey = 'p'; break;
            case 0xA8: RetKey = 'q'; break;
            case 0xB4: RetKey = 'r'; break;
            case 0xD8: RetKey = 's'; break;
            case 0x34: RetKey = 't'; break;
            case 0x3C: RetKey = 'u'; break;
            case 0x54: RetKey = 'v'; break;
            case 0xB8: RetKey = 'w'; break;
            case 0x44: RetKey = 'x'; break;
            case 0xAC: RetKey = 'y'; break;
            case 0x58: RetKey = 'z'; break;
        }
        // Shift moves letter to upper case
        if(KbdStatus & 0x06) RetKey &= 0xDF;
        // Test number codes and and special characters
        switch (KeyCode) {
            case 0x68: RetKey = (KbdStatus & 0x06) ? '!' : '1'; break;
            case 0x78: RetKey = (KbdStatus & 0x06) ? '@' : '2'; break;
            case 0x64: RetKey = (KbdStatus & 0x06) ? '#' : '3'; break;
            case 0xA4: RetKey = (KbdStatus & 0x06) ? '$' : '4'; break;
            case 0x74: RetKey = (KbdStatus & 0x06) ? '%' : '5'; break;
            case 0x6C: RetKey = (KbdStatus & 0x06) ? '^' : '6'; break;
            case 0xBC: RetKey = (KbdStatus & 0x06) ? '&' : '7'; break;
            case 0x7C: RetKey = (KbdStatus & 0x06) ? '*' : '8'; break;
            case 0x62: RetKey = (KbdStatus & 0x06) ? '(' : '9'; break;
            case 0xA2: RetKey = (KbdStatus & 0x06) ? ')' : '0'; break;
            // Num keys
            case 0x8E: RetKey = '.'; break;    // .
            case 0x0E: RetKey = '0'; break;    // 0
            case 0x96: RetKey = '1'; break;    // 1
            case 0x4E: RetKey = '2'; break;    // 2
            case 0x5E: RetKey = '3'; break;    // 3
            case 0xD6: RetKey = '4'; break;    // 4
            case 0xCE: RetKey = '5'; break;    // 5
            case 0x2E: RetKey = '6'; break;    // 6
            case 0x36: RetKey = '7'; break;    // 7
            case 0xAE: RetKey = '8'; break;    // 8
            case 0xBE: RetKey = '9'; break;    // 9
            case 0x9E: RetKey = '+'; break;    // +
            case 0xDE: RetKey = '-'; break;    // -
            case 0x3E: RetKey = '*'; break;    // *
            case 0x52: RetKey = '/'; break;    // /
        }
        // And remaining special characters
        switch (KeyCode) {
            case 0x94: RetKey = ' '; break;
            case 0x5A: RetKey = 0x0A; break;    // Enter
            case 0xB0: RetKey = 0x09; break;    // Tab
            case 0x66: RetKey = 0x08; break;    // Backspace
            case 0x72: RetKey = (KbdStatus & 0x06) ? '_' : '-'; break;
            case 0xAA: RetKey = (KbdStatus & 0x06) ? '+' : '='; break;
            case 0x2A: RetKey = (KbdStatus & 0x06) ? '{' : '['; break;
            case 0xDA: RetKey = (KbdStatus & 0x06) ? '}' : ']'; break;
            case 0x32: RetKey = (KbdStatus & 0x06) ? ':' : ';'; break;
            case 0x4A: RetKey = (KbdStatus & 0x06) ? '"' : 0x27; break;
            case 0xBA: RetKey = (KbdStatus & 0x06) ? '|' : 0x5C; break;
            case 0x82: RetKey = (KbdStatus & 0x06) ? '<' : ','; break;
            case 0x92: RetKey = (KbdStatus & 0x06) ? '>' : '.'; break;
            case 0x52: RetKey = (KbdStatus & 0x06) ? '?' : '/'; break;
        }
	}
  if(KbdStatus & 0x01) {
    // Ctrl changes character to KEYWORD code
    switch (RetKey) {
      case 'p': RetKey = 0xA0; break; // PRINT
      case 'u': RetKey = 0xA1; break; // IF
      case 't': RetKey = 0xA2; break; // THEN
      case 'g': RetKey = 0xA3; break; // GOTO
      case 'i': RetKey = 0xA4; break; // INPUT
      case 'l': RetKey = 0xA5; break; // LET
      case 'h': RetKey = 0xA6; break; // GOSUB
      case 'y': RetKey = 0xA7; break; // RETURN
      case 'x': RetKey = 0xA8; break; // CLEAR
      case 'k': RetKey = 0xA9; break; // LIST
      case 'r': RetKey = 0xAA; break; // RUN
      case 'n': RetKey = 0xAB; break; // END

      case 'v': RetKey = 0xAC; break; // TIME
      case 'w': RetKey = 0xAD; break; // CURSOR
      case 'c': RetKey = 0xAE; break; // PUTCH
      case ',': RetKey = 0xAF; break; // GETCH
      case 's': RetKey = 0xB0; break; // INKEY
      case 'f': RetKey = 0xB1; break; // FILE
      case 'd': RetKey = 0xB2; break; // DISK
      case 'm': RetKey = 0xB3; break; // DELAY
      case 'z': RetKey = 0xB4; break; // BEEP
      case 'e': RetKey = 0xB5; break; // REM

      case 'a': RetKey = 0xB6; break; // AINP
      case 'b': RetKey = 0xB7; break; // DINP
      case 'o': RetKey = 0xB8; break; // DOUT
      case 'q': RetKey = 0xB9; break; // I2CW
      case 'j': RetKey = 0xBA; break; // I2CR
      case '.': RetKey = 0xBB; break; // COPY
    }
  }
	return RetKey;
}

// Wait for keystroke and blink cursor on the corresponding position
uint8_t GetKeyChar()
{
    uint8_t saveChar, retChar;
    saveChar = VideoRAM[dispPointer];  // Save char on the cursor position (for cursor blink)
    do{
        if(basTimer & 0x2000) VideoRAM[dispPointer] = saveChar; else VideoRAM[dispPointer] = 0x60;  // blink
        retChar = kbdRead();
        Delay_Ms(1);
    } while(retChar == 0);
    VideoRAM[dispPointer] = saveChar;  // Restore position
    return retChar;
}

/*********************************************************************
    Functions for display
 *********************************************************************/
// Display character 0x00 - 0xFF to VGA on cursor position
void WriteChar(uint8_t dispChar)
{
    switch (dispChar) {
        case 0x0C: {      // FormFeed
            for(int i=0;i<800;i++) VideoRAM[i]=0; 
            dispPointer = 0;
        } break;
        case 0x0A: {    // Enter / New line
            dispPointer = ((dispPointer >> 5) + 1) << 5;
        } break;
        case 0x09: {    // Tab
            dispPointer = ((dispPointer >> 3) + 1) << 3;
        } break;
        default: {  // Remaining characters
            if((dispChar>0x1F) && (dispChar<0xA0)) VideoRAM[dispPointer++] = dispChar-0x20; // Printable
            else if((dispChar>0x9F) && (dispChar<0xBC)) { // Tiny BASIC Keywords
              int pKeyWord = ((dispChar - (uint8_t)0xA0)) << 3;
              for(int j=0; j<KeyWordTab[pKeyWord];j++){
                VideoRAM[dispPointer++] = KeyWordTab[pKeyWord+j+1] - 0x20;
                // Test pointer and roll display if it is over last line
                if(dispPointer>799) {
                    for(int i=0;i<768;i++) VideoRAM[i]=VideoRAM[i+32];  // Roll it up
                    for(int i=768;i<800;i++) VideoRAM[i]=0; // Clear last line
                    dispPointer = 768;
                }
              }
            }
            else if(dispChar!=0x08) VideoRAM[dispPointer++] = 0x0E; // Dot for non printable - except backspace
        }; break;
    }
    // Test pointer and roll display if it is over last line
    if(dispPointer>799) {
        for(int i=0;i<768;i++) VideoRAM[i]=VideoRAM[i+32];  // Roll it up
        for(int i=768;i<800;i++) VideoRAM[i]=0; // Clear last line
        dispPointer = 768;
    }
}

// Print text (and second version with new line)
void WriteText(char *pointChar)
{
    while(*pointChar) WriteChar(*pointChar++);
}
void WriteTextln(const char *pointChar)
{
    while(*pointChar) WriteChar(*pointChar++);
    WriteChar(0x0A);
}
// Display integer number (32bits) on VGA
void WriteNum(int writNumber)
{
  uint8_t digits[10];     // Integer number has 10 digits max
  uint8_t Signum = 0; 
  uint8_t i = 0;
  if(writNumber) {
    if(writNumber < 0) {Signum = 1; writNumber = -writNumber;}
    while(writNumber) {
      digits[i] = (uint8_t) (writNumber%10) | 0x30;
      writNumber /= 10;
      i++;
    }
    if(Signum) WriteChar('-');
    while(i) WriteChar(digits[--i]);
  } else  WriteChar('0');
}

// Function for error message
void WriteErrMsg(const char *pointChar)
{
    WriteChar(0x0A);WriteChar('L');   // Write L (aka Line)
    WriteNum(currentLine);      // Number of line with error
    WriteChar(0x20);
    while(*pointChar) WriteChar(*pointChar++);  // and error message
    WriteChar(0x0A);
    RunMode = 0;    // Error == stop program
}

/*********************************************************************
    Functions for initialization and interrupts
 *********************************************************************/
/*********************************************************************
 * @fn      DMA_Tx_Init
 * @brief   Initializes the DMAy Channelx configuration.
 * @param   DMA_CHx - x can be 1 to 7.
 *          ppadr - Peripheral base address.
 *          memadr - Memory base address.
 *          bufsize - DMA channel buffer size.
 * @return  none
 */
void DMA_Tx_Init(DMA_Channel_TypeDef *DMA_CHx, u32 ppadr, u32 memadr, u8 bufsize)
{
    DMA_InitTypeDef DMA_InitStructure = {0};
    RCC_AHBPeriphClockCmd(RCC_AHBPeriph_DMA1, ENABLE);
    DMA_InitStructure.DMA_PeripheralBaseAddr = ppadr;
    DMA_InitStructure.DMA_MemoryBaseAddr = memadr;
    DMA_InitStructure.DMA_DIR = DMA_DIR_PeripheralDST;
    DMA_InitStructure.DMA_BufferSize = bufsize;
    DMA_InitStructure.DMA_PeripheralInc = DMA_PeripheralInc_Disable;
    DMA_InitStructure.DMA_MemoryInc = DMA_MemoryInc_Enable;
    DMA_InitStructure.DMA_PeripheralDataSize = DMA_PeripheralDataSize_Byte;
    DMA_InitStructure.DMA_MemoryDataSize = DMA_MemoryDataSize_Byte;
    DMA_InitStructure.DMA_Mode = DMA_Mode_Circular;
    DMA_InitStructure.DMA_Priority = DMA_Priority_VeryHigh;
    DMA_InitStructure.DMA_M2M = DMA_M2M_Disable;
    DMA_Init(DMA_CHx, &DMA_InitStructure);
}
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
int main(void)
{
  SystemCoreClockUpdate();    // Standard functions...
  Delay_Init();   // ... at start-up
  GPIO_InOut_INIT();    // Initialize GPIO ports
  TIM1_INT_Init();    // Initialize timer SPI and interrupts
  DMA_Tx_Init(DMA1_Channel3, (u32)&SPI1->DATAR, (u32)DMABuff, 47);    // Setup DMA

  // The next part is time-critical, so assembler is used
  // Be careful to change this part!
  TIM1->CTLR1 |= TIM_CEN;   // Timer1 on
  // Piece of assembler code for precise timing between TIMER and DMA start
  asm volatile (
    "   addi sp, sp, -16 \n"  // Allocate stack
    "   sw t0, 12(sp) \n"    // Save my working register
    "   li t0, 56 \n"       // Get Delay time - slight change will move display horizontally left or right
    "shorttim:  addi  t0,t0,-1  \n"   // Decrement value in register
    "   bne  t0, x0, shorttim  \n"     // Test for zero and branch
    "   lw t0, 12(sp) \n"    // Restore working register
    "   addi sp, sp, 16 \n"  // Return allocated stack
  );
  DMA1_Channel3->CFGR |= 0x00001; // DMA channel on
  // End of time-critical part

  kbd_init(); // Start keyboard
  adc_init(); // Start A/D converter
  WriteTextln("TinyBasic 1.0");  // Introductory message
  line_buffer[32] = (unsigned char)0xFF;  // Stop symbol at end of buffer
  IIC_Init(100000, 0x20);  // Start I2C module @ 100 000kHz at first
  // Check devices connected to I2C bus
  if(!CheckI2CDevice(0xA2)) WriteText("No DISK f, "); else compFlags |= 0x80;
  if(!CheckI2CDevice(0x40)) WriteText("No PCF8575, "); else compFlags |= 0x40;
#ifdef SYSCLK_EXT_CRYSTAL 
  WriteTextln("Ext Xtal");
#else
  WriteTextln("Int OSC");
#endif
  I2C1->CKCFGR = 0xC005;      // Speed up I2C to slightly bellow 400000 kHz
  // Completion of the initial report

  // Test for autorun (Is statement RUN - 0xAA in the first byte of file 0?)
  I2C_read_line(0);   // Read the first line of file
  if(line_buffer[0] == (unsigned char)0xAA) {   // Test first byte for RUN statement
    linePointer=1;    // First byte is bytecode of RUN, so move to next byte...
    KbdData = 0x5A;   // ... and pretend that user pressed Enter after RUN
  }
  char recChar;   // Processed character from keyboard
  while(1)
  {
    // Get char to buffer (only to max size of buffer or end of line (Enter))
    recChar = GetKeyChar();
    // and return it to display
    if(recChar == 0x09) {  // Tab needs special cure 
      if(linePointer < 27) WriteText("    "); // Tab inserts only 4 spaces
    } else {  // Other characters
      if(linePointer < 32) WriteChar(recChar);
    }
    // Char must be saved to line_buffer
    // Is it char to start process line (Enter)?
    if (recChar == '\n') {
      // look for the newline. That's the end of your sentence:
      line_buffer[linePointer] = (unsigned char)0xFF;    // End of line is signalled with 0xFF
      currentLine = 0; linePointer=0;  // Prepare pointer to beginning,...
      // ... and process line
      int* numLine;
      RemoveWhtSP();
      if((numLine = isNumberNext()) != NULL) {    // If line starts with number ...
        RemoveWhtSP();  // ... discard number and white spaces ...
        if((*numLine >= 0) && (*numLine < 128)) I2C_write_line((unsigned char) *numLine); // ... and save line
        else WriteErrMsg("Error line number!");
      }
      else {  // No number at begin of line
        do{ // Execute statements while RunMode
            uint8_t auxLine = currentLine;    // Save line number
            // -----------------------------------------------------------
            Statement();
            // Test for the second Statement on the line
            RemoveWhtSP();  // IF, GOTO or GOSUB will discard second Statement
            if((auxLine == currentLine) && (line_buffer[linePointer] == ';')) {
              RemoveNextWhtSP();
              Statement();
            }
            // Test for the third Statement on the line
            RemoveWhtSP();  // IF, GOTO or GOSUB will discard third Statement
            if((auxLine == currentLine) && (line_buffer[linePointer] == ';')) {
              RemoveNextWhtSP();
              Statement();
            }
            if(RunMode && (auxLine == currentLine)) currentLine++; // No jump, so go to next line
            // Prepare next program line
            if(currentLine > 127) { RunMode = 0; currentLine = 0;} // Number of line step over maximum line
            else { I2C_read_line(currentLine); linePointer = 0; }   // Line number is OK, so prepare it
        } while(RunMode);
        WriteTextln("\nOK");
      }
      // ... line was proccessed so...
      linePointer=0;  // ... move pointer to beginning again.
    }
    else {       // No end of line - just process character
      if(recChar==0x08) {    // Is backspace, so return char(s) in the line
        if (linePointer > 0) {  // Edit can be only in current line
          linePointer--;    // Return pointer 1 char
          if(line_buffer[linePointer] < 0xA0) { dispPointer--;VideoRAM[dispPointer] = 0x00;} // Discard normal character
          else {  // It is keyword - that means rather difficult
            if(line_buffer[linePointer] < 0xBC) { // Just within keyword range
              int pKeyWord = ((line_buffer[linePointer] - (uint8_t)0xA0)) << 3;  // Get lenght of keyword
              for(int j=0; j<KeyWordTab[pKeyWord];j++){
                VideoRAM[dispPointer] = 0x00;     // Discard 1 letter of keyword
                // Test pointer and stop roll display off
                if(dispPointer>1) dispPointer--;
              }
              VideoRAM[dispPointer] = 0x00;     // And the discard last letter of keyword
            }
          } 
        }
      } else {
        if (linePointer < 32) {
          // Put normal char to line buffer
          if(recChar == 0x09) {    // Special char is Tab
            if(linePointer < 27) {  // Expand Tab to 4 spaces (for future backspace)
              line_buffer[linePointer++] = ' '; line_buffer[linePointer++] = ' ';
              line_buffer[linePointer++] = ' '; line_buffer[linePointer++] = ' '; 
            }
          } else {
          // Save real "normal" char finally
            line_buffer[linePointer] = recChar;
            linePointer++;  // max 32 chars in buffer
          }
        }
      }
    }
  }
}
